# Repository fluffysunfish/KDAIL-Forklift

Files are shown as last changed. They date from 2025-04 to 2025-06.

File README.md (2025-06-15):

# Smart-Forklift

**KDAIL-Forklift** is an intelligent autonomous forklift robot designed as part of a warehouse automation project, built in collaboration with <a href="https://krishnaallied.com/">KDAIL</a>.

# Brief

# Problem statement

Modern warehouses, especially those used by defense orgs face significant challenges in automating indoor material handling tasks due to :
- the lack of GPS 
- the fragmented nature of robotic software stacks  
- security loopholes with proprietery tech 

Existing solutions are often :
- hardware-dependent 
- tailored for specific environments—making them difficult to scale or replicate
- over-complicated and non-intuitive 
- heavily setup dependent 

Moreover, enabling robots to navigate dynamic, cluttered indoor spaces while accurately locating and manipulating goods remains an open problem, especially for small- to medium-scale industries seeking low-cost, swarm-based intelligent automation.

---
# Proposed solution 

We addres these challenges with an end-to-end, modular, and reproducible robotics system tailored for indoor defence warehouse logistics. At its core, the robot fuses <b>UWB-based odometry, 2D LiDAR,</b> and <b>ArUco marker</b> detection to achieve robust SLAM and localization, even in GPS-denied and visually sparse environments. It is capable of autonomously navigating the environment, identifying loads, and executing pick-and-place operations using a forklift actuation mechanism.
The robot is instructed via an intuitive web-based interface backed by a ROS-powered backend, allowing real-time monitoring, control, and task assignment. All hardware—from the custom chassis to sensing and actuation—is designed to be inexpensive and in-house, enabling widespread replication and adoption in budget-constrained setups.

# Features

- 2D LiDAR-based object detection, mapping
- Autonomous navigation and obstacle avoidance
- UWB integration for accurate odometry(sub 5-cms)
- Aruco markers integration for accurate identification and pick-up
- Forklift actuation for pick-and-place
- Simulation + Real-world compatibility
- Modular ROS-based architecture

---

#  Demonstration and Media

- [Automation and detection demo](https://youtube.com/shorts/qDDlVrJwSQA?feature=share)
- [UWB RTLS demo](https://youtube.com/shorts/iG-MlcV99eU?feature=share)

---

## Tech Stack

- **ROS2 Humble** on Ubuntu 22.04
- **Raspberry pi 4b** for onboard compute 
- **LiDAR** (RPLIDAR A2M8) for mapping and detection
- **UWB-anchors and seekers**(DWM30001CDK) for odometry and ranging
- **OpenCV** for computer vision utilities
- **Gazebo** + **RViz** for simulation and visualization
- **ROS-node backed web interface**for cross-platform communication and easy control. 

---

##  Repository Structure

```bash
KDAIL-Forklift/
├── aruco/                  # Scripts to take camera feed, check aruco markers
├── bot_controls/           # Scripts to do teleop and control crane mechanism of the bot
├── ros2_ws/                # Ros workspace of the repository, contains all the nodes and topics created
├── web_control/            # Inuitive UI for over the air communication/control of the bot
├── README.md               # You're here!

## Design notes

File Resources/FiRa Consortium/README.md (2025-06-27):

# FiRa Consortium and Standards
## Table of Contents 
- [What is the FiRa Consortium and why was it established?](#what-is-the-fira-consortium-and-why-was-it-established?)
- [What are the key FiRa specifications and standards?](#what-are-the-key-fira-specifications-and-standards?)
- [Multi-device Ranging
### What is the FiRa Consortium and why was it established?

#### Historical Context and Formation

The Fine Ranging (FiRa) Consortium was established in August 2019 as a direct response to the fragmented state of the UWB industry. Prior to FiRa's formation, the UWB ecosystem suffered from several critical challenges:

**Pre-FiRa Market Conditions:**
- **Proprietary Implementations**: Each vendor developed incompatible UWB solutions
- **Interoperability Gaps**: Devices from different manufacturers couldn't communicate
- **Limited Standardization**: IEEE 802.15.4 provided only PHY/MAC layers
- **Market Fragmentation**: Multiple competing approaches hindered adoption
- **Certification Absence**: No standardized testing or certification programs

**Founding Members and Industry Support:**
The consortium was founded by major technology companies recognizing the need for standardization:

*Original Founding Members:*
- **Apple**: Mobile device integration and user experience
- **Bosch**: Automotive and IoT applications
- **NXP Semiconductors**: Semiconductor solutions and chip design
- **Samsung**: Consumer electronics and smartphone integration
- **Sony**: Consumer electronics and entertainment systems

*Current Membership Growth:*
- **80+ Member Companies**: Representing entire UWB ecosystem
- **Mobile Device Manufacturers**: Apple, Samsung, Google, Xiaomi, Oppo
- **Semiconductor Companies**: NXP, Qorvo, Infineon, STMicroelectronics
- **Automotive Industry**: BMW, Volkswagen, Continental, Hyundai
- **Technology Integrators**: Zebra Technologies, Sewio, Ubisense

#### Mission and Strategic Objectives

**Primary Mission Statement:**
"To drive the adoption of secure fine ranging and positioning capabilities, enabling a new generation of applications and services."

**Strategic Objectives:**

1. **Interoperability Assurance:**
   - Develop comprehensive technical specifications
   - Establish mandatory compliance requirements
   - Create interoperability testing procedures
   - Maintain certification database

2. **Market Acceleration:**
   - Reduce development time and cost
   - Increase consumer and enterprise confidence
   - Enable ecosystem-wide innovation
   - Support regulatory compliance

3. **Security Enhancement:**
   - Establish cryptographic standards
   - Prevent relay and spoofing attacks
   - Enable secure ranging protocols
   - Support privacy protection

4. **Use Case Enablement:**
   - Define application-specific requirements
   - Support vertical market adoption
   - Enable cross-industry collaboration
   - Facilitate regulatory approval

### What are the key FiRa specifications and standards?

#### Core Technical Specifications

**FiRa PHY and MAC Technical Requirements (Current Version 1.3.0):**

*Physical Layer Specifications:*
- **IEEE 802.15.4z Foundation**: Built upon IEEE standard amendment
- **Channel Selection**: Specific channels from 802.15.4z allocation
- **Modulation Schemes**: BPM-BPSK, BPSK with specific parameters
- **Pulse Repetition Frequency**: Defined PRF values for different applications
- **Power Management**: Transmit power control and optimization

*Detailed PHY Parameters:*
```
Channel Specifications:
- Channel 5: 6489.6 MHz center frequency
- Channel 9: 7987.2 MHz center frequency
- Bandwidth: 499.2 MHz nominal
- Pulse Repetition Frequency: 62.4 MHz or 124.8 MHz
- Modulation: BPM-BPSK with spreading factor 128 or 1024
```

*Media Access Control (MAC) Layer:*
- **Frame Structure**: Enhanced 802.15.4z frame format
- **Ranging Protocols**: Two-Way Ranging (TWR) and Time Difference of Arrival (TDoA)
- **Security Integration**: Cryptographic protection mechanisms
- **Multi-device Support**: Concurrent ranging sessions
- **Power Optimization**: Dynamic power management

*MAC Protocol Details:*
- **Ranging Frame Exchange**: Specific timing requirements
- **Acknowledgment Procedures**: Reliable communication protocols
- **Collision Avoidance**: Medium access control mechanisms
- **Synchronization**: Precise timing coordination
- **Error Handling**: Robust error detection and recovery

**FiRa Use Case Requirements (Version 2.0.0):**

*Primary Use Cases:*

1. **Access Control (Use Case 1):**
   - **Application**: Secure vehicle and building access
   - **Ranging Method**: Two-Way Ranging (TWR)
   - **Security Level**: High (AES-128 encryption)
   - **Latency Requirement**: <100 ms for access decision
   - **Accuracy Requirement**: 10-30 cm for proximity detection
   - **Attack Resistance**: Relay attack prevention mandatory

2. **Device-to-Device (Use Case 2):**
   - **Application**: Peer-to-peer device interaction
   - **Ranging Method**: TWR with role switching
   - **Security Level**: Medium to High (application dependent)
   - **Latency Requirement**: <50 ms for responsive interaction
   - **Accuracy Requirement**: 5-20 cm for precise positioning
   - **Multi-device**: Support for multiple simultaneous connections

3. **Point-of-Interest (Use Case 3):**
   - **Application**: Location-based services and navigation
   - **Ranging Method**: TDoA preferred for scalability
   - **Security Level**: Low to Medium (context dependent)
   - **Latency Requirement**: <200 ms for user experience
   - **Accuracy Requirement**: 30-100 cm for zone identification
   - **Scalability**: Support for hundreds of devices

*Extended Use Cases:*
- **Asset Tracking**: Industrial and enterprise applications
- **Augmented Reality**: Spatial computing and AR/VR
- **Smart Home**: IoT device coordination and control
- **Healthcare**: Patient and equipment tracking

**FiRa Test Specifications (Version 1.2.0):**

*Conformance Testing:*
- **Protocol Compliance**: MAC and PHY layer verification
- **Parameter Validation**: Timing, power, and frequency accuracy
- **Message Format**: Frame structure and field validation
- **Error Handling**: Exception and error case testing

*Interoperability Testing:*
- **Cross-vendor Compatibility**: Multi-vendor device testing
- **Use Case Scenarios**: Real-world application testing
- **Performance Validation**: Accuracy and reliability measurement
- **Stress Testing**: High-load and interference scenarios

*Security Testing:*
- **Cryptographic Validation**: Encryption implementation verification
- **Attack Resistance**: Relay and spoofing attack testing
- **Key Management**: Secure key distribution and rotation
- **Privacy Protection**: Personal data protection validation

#### Advanced Technical Features

**Secure Ranging Protocol:**

*Security Architecture:*
The FiRa security model provides multiple layers of protection:

1. **Authentication Layer:**
   - **Mutual Authentication**: Both devices verify identity
   - **Certificate-based**: X.509 certificate validation
   - **Session Establishment**: Secure session key generation
   - **Replay Protection**: Timestamp and nonce validation

2. **Ranging Protection:**
   - **Secure Time Stamps**: Cryptographically protected timing
   - **Message Authentication**: HMAC validation
   - **Sequence Verification**: Prevent message replay
   - **Distance Bounding**: Physical proximity verification

3. **Privacy Protection:**
   - **Identifier Rotation**: Dynamic device identification
   - **Location Privacy**: Prevent unauthorized tracking
   - **Data Minimization**: Limit information exposure
   - **Consent Management**: User privacy controls

*Cryptographic Specifications:*
```
Encryption Algorithms:
- AES-128: Primary encryption standard
- HMAC-SHA256: Message authentication
- ECDH P-256: Key exchange protocol
- HKDF: Key derivation function

Security Parameters:
- Session Key Length: 128 bits
- Nonce Length: 96 bits
- Authentication Tag: 128 bits
- Certificate Chain: Up to 3 levels
```

**Multi-device Ranging:**

*Concurrent Ranging Sessions:*
FiRa supports sophisticated multi-device scenarios:

1. **Round-Robin Ranging:**
   - **Sequential Measurement**: One device ranges to multiple anchors
   - **Timing Coordination**: Precise scheduling to avoid interference
   - **Scalability**: Support for 8+ concurrent sessions
   - **Efficiency**: Optimized for battery-powered devices

2. **Simultaneous Ranging:**
   - **Parallel Measurement**: Multiple devices range simultaneously
   - **Code Division**: Orthogonal codes prevent interference
   - **Synchronization**: Precise timing across all devices
   - **Collision Management**: Automatic conflict resolution

3. **Hierarchical Networks:**
   - **Master-Slave Architecture**: Coordinated multi-device systems
   - **Cascaded Ranging**: Extended coverage through device chaining
   - **Load Balancing**: Distribute ranging load across network
   - **Fault Tolerance**: Redundant paths and backup systems

**Angle-of-Arrival Integration:**

*Enhanced Positioning:*
FiRa specifications include provisions for AoA enhancement:

1. **Antenna Array Support:**
   - **Spatial Diversity**: Multiple antenna elements
   - **Beam Forming**: Directional transmission and reception
   - **Calibration**: Precise antenna array characterization
   - **Temperature Compensation**: Environmental stability

2. **Angle Measurement:**
   - **Phase Difference**: Based on signal phase relationships
   - **Amplitude Comparison**: Signal strength at different elements
   - **Time Difference**: Arrival time variations across array
   - **Hybrid Methods**: Combined ranging and angle measurement

3. **Enhanced Accuracy:**
   - **2D Positioning**: Improved with angle information
   - **3D Positioning**: Full spatial positioning capability
   - **Orientation Detection**: Device attitude determination
   - **Reduced Infrastructure**: Fewer anchors required

### How does FiRa certification ensure interoperability between UWB devices?

#### Comprehensive Certification Framework

**Certification Philosophy:**
FiRa's certification approach is built on the principle that true interoperability requires testing beyond basic protocol compliance. The program validates not just technical conformance, but real-world operational compatibility across diverse scenarios and vendor implementations.

**Multi-tiered Certification Structure:**

*Tier 1: Component Certification*
- **Scope**: Individual UWB chips, modules, and subsystems
- **Testing Focus**: PHY and MAC layer compliance
- **Requirements**: Protocol conformance and parameter validation
- **Documentation**: Detailed test reports and compliance matrices
- **Validity**: Component-level certification for integration

*Tier 2: Product Certification*
- **Scope**: Complete end-user devices and systems
- **Testing Focus**: Full system integration and performance
- **Requirements**: Use case compliance and interoperability
- **Documentation**: System-level validation and user guides
- **Validity**: Product-level certification for market deployment

*Tier 3: Ecosystem Certification*
- **Scope**: Multi-vendor system integration
- **Testing Focus**: Cross-vendor interoperability validation
- **Requirements**: Real-world scenario testing
- **Documentation**: Ecosystem compatibility reports
- **Validity**: System-level deployment certification

#### Detailed Testing Methodology

**Conformance Testing Procedures:**

*Physical Layer Validation:*
```
Test Categories:
1. Transmitter Tests:
   - Power spectral density measurement
   - Frequency accuracy and stability
   - Pulse shape and timing accuracy
   - Modulation quality assessment

2. Receiver Tests:
   - Sensitivity and dynamic range
   - Frequency selectivity and blocking
   - Spurious response rejection
   - Demodulation accuracy

3. Ranging Tests:
   - Time-of-flight accuracy
   - Ranging precision and repeatability
   - Multi-path handling capability
   - NLOS detection and mitigation
```

*MAC Layer Validation:*
- **Frame Structure**: Compliance with FiRa frame formats
- **Timing Requirements**: Precise inter-frame spacing
- **Acknowledgment Protocols**: Reliable message exchange
- **Error Handling**: Robust error detection and recovery
- **Security Integration**: Cryptographic protocol implementation

*Application Layer Testing:*
- **Use Case Compliance**: Specific application requirements
- **Performance Metrics**: Accuracy, latency, and reliability measurements
- **Security Validation**: End-to-end security implementation
- **User Experience**: Human-machine interface compliance
- **Environmental Testing**: Performance across operating conditions

**Interoperability Testing Protocol:**

*Cross-Vendor Compatibility Matrix:*
```
Testing Scenarios:
┌─────────────┬─────────────┬─────────────┬─────────────┐
│   Vendor    │   Vendor A  │   Vendor B  │   Vendor C  │
├─────────────┼─────────────┼─────────────┼─────────────┤
│  Vendor A   │    N/A      │   Required  │   Required  │
│  Vendor B   │  Required   │    N/A      │   Required  │
│  Vendor C   │  Required   │   Required  │    N/A      │
└─────────────┴─────────────┴─────────────┴─────────────┘

Test Matrix Requirements:
- All vendor pairs must pass interoperability tests
- Minimum 3 vendors required for ecosystem validation
- Testing covers all supported use cases
- Performance benchmarks must be maintained
```

*Real-World Scenario Testing:*
1. **Office Environment:**
   - Multiple anchor deployment
   - Personnel and asset tracking
   - WiFi interference scenarios
   - Mixed vendor equipment

2. **Industrial Environment:**
   - Metal structure reflections
   - High-temperature operation
   - Electromagnetic interference
   - Safety system integration

3. **Automotive Environment:**
   - Vehicle access scenarios
   - Parking lot deployment
   - Mobile device integration
   - Security attack resistance

4. **Consumer Environment:**
   - Home automation integration
   - Mobile device interaction
   - Privacy protection validation
   - User experience testing

#### Certification Process Workflow

**Pre-Certification Phase:**

*Self-Assessment Tools:*
- **FiRa Test Suite**: Automated testing software
- **Reference Implementation**: Validated software stack
- **Compliance Checklist**: Detailed requirement verification
- **Pre-certification Report**: Internal validation documentation

*Technical Documentation Requirements:*
- **Hardware Design**: Detailed circuit and antenna designs
- **Software Architecture**: Protocol stack implementation
- **Security Implementation**: Cryptographic module documentation
- **Performance Characterization**: Laboratory test results
- **Environmental Testing**: Temperature, humidity, vibration results

**Authorized Test Laboratory (ATL) Testing:**

*Accredited Facilities:*
FiRa maintains a network of authorized test laboratories worldwide:

- **Geographic Coverage**: Major markets globally covered
- **Accreditation Standards**: ISO/IEC 17025 compliance
- **Equipment Calibration**: Traceable measurement standards
- **Test Procedure Training**: FiRa-certified test engineers
- **Quality Assurance**: Regular proficiency testing

*Testing Infrastructure Requirements:*
```
Laboratory Equipment:
1. RF Test Equipment:
   - Vector network analyzers (10 MHz - 20 GHz)
   - Spectrum analyzers with UWB capability
   - Signal generators with arbitrary waveform
   - Power meters and sensors

2. Positioning Test Setup:
   - Anechoic chamber (3m x 3m minimum)
   - Precision positioning systems
   - Environmental control systems
   - Multi-path simulation capability

3. Security Test Equipment:
   - Hardware security modules
   - Cryptographic test vectors
   - Side-channel analysis tools
   - Protocol analysis equipment
```

**Certification Decision Process:**

*Technical Review Board:*
- **Composition**: Industry experts from member companies
- **Review Process**: Independent technical assessment
- **Decision Criteria**: Objective pass/fail requirements
- **Appeal Process**: Structured dispute resolution
- **Continuous Monitoring**: Post-certification surveillance

*Certification Maintenance:*
- **Annual Reviews**: Ongoing compliance verification
- **Change Notifications**: Product modification reporting
- **Re-testing Requirements**: Significant change validation
- **Market Surveillance**: Field performance monitoring
- **Corrective Actions**: Non-compliance remediation

#### Quality Assurance and Validation

**Test Result Validation:**

*Statistical Analysis:*
- **Measurement Uncertainty**: Quantified test accuracy
- **Repeatability**: Multiple test run consistency
- **Reproducibility**: Inter-laboratory agreement
- **Confidence Intervals**: Statistical significance testing
- **Outlier Detection**: Anomalous result identification

*Performance Benchmarking:*
```
Key Performance Indicators (KPIs):
1. Ranging Accuracy:
   - Mean absolute error: <30 cm (95% confidence)
   - Standard deviation: <15 cm
   - Maximum error: <100 cm

2. Latency Performance:
   - Average ranging time: <10 ms
   - Maximum ranging time: <50 ms
   - System response time: <100 ms

3. Reliability Metrics:
   - Packet success rate: >99%
   - False alarm rate: <0.1%
   - Availability: >99.9%

4. Security Validation:
   - Attack resistance: 100% (no successful attacks)
   - Key management: Proper implementation
   - Privacy protection: Compliance verified
```

**Continuous Improvement Process:**

*Feedback Integration:*
- **Field Experience**: Real-world deployment feedback
- **Member Input**: Industry stakeholder requirements
- **Technology Evolution**: Emerging capability integration
- **Regulatory Changes**: Compliance requirement updates
- **Security Threats**: New attack vector mitigation

*Specification Updates:*
- **Regular Revision Cycle**: Annual specification reviews
- **Backward Compatibility**: Legacy device support
- **Migration Paths**: Upgrade roadmap definition
- **Implementation Guidance**: Best practice documentation
- **Training Programs**: Industry education initiatives

### What is the difference between IEEE 802.15.4z and FiRa specifications?

#### Fundamental Scope and Purpose Differences

**IEEE 802.15.4z Amendment (2020):**

*Standards Development Context:*
IEEE 802.15.4z represents a formal amendment to the IEEE 802.15.4 standard, specifically targeting Ultra Wideband (UWB) applications. The development process followed IEEE's rigorous standards development procedures:

- **Development Timeline**: 2016-2020 (4-year development cycle)
- **Working Group**: IEEE 802.15.4z Task Group
- **Consensus Process**: Global industry participation and voting
- **Scope Limitation**: Intentionally limited to PHY and MAC layers
- **Implementation Flexibility**: Multiple optional features and parameters

*Technical Architecture:*
```
IEEE 802.15.4z Layer Structure:
┌─────────────────────────────────────┐
│        Application Layer            │ ← Not Specified
├─────────────────────────────────────┤
│        Network Layer               │ ← Not Specified
├─────────────────────────────────────┤
│    Logical Link Control (LLC)      │ ← Not Specified
├─────────────────────────────────────┤
│   Medium Access Control (MAC)      │ ← IEEE 802.15.4z
├─────────────────────────────────────┤
│      Physical Layer (PHY)          │ ← IEEE 802.15.4z
└─────────────────────────────────────┘
```

**FiRa Consortium Specifications:**

*Industry Requirements Focus:*
FiRa specifications were developed to address real-world deployment needs that IEEE 802.15.4z, by design, does not cover:

- **Development Timeline**: 2019-ongoing (continuous evolution)
- **Industry Consortium**: Commercial deployment focus
- **Comprehensive Scope**: Full protocol stack specification
- **Prescriptive Requirements**: Specific mandatory implementations
- **Market-Driven Features**: User experience and security emphasis

*Complete System Architecture:*
```
FiRa Specification Coverage:
┌─────────────────────────────────────┐
│     Application Profiles           │ ← FiRa Use Cases
├─────────────────────────────────────┤
│     Security Framework             │ ← FiRa Security
├─────────────────────────────────────┤
│     Service Layer                  │ ← FiRa Services
├─────────────────────────────────────┤
│   Medium Access Control (MAC)      │ ← FiRa + IEEE 802.15.4z
├─────────────────────────────────────┤
│      Physical Layer (PHY)          │ ← FiRa + IEEE 802.15.4z
└─────────────────────────────────────┘
```

#### Detailed Technical Specification Comparison

**Physical Layer Implementation:**

*IEEE 802.15.4z PHY Specification:*
- **Channel Definition**: Defines available UWB channels
- **Modulation Options**: Multiple modulation schemes (BPM-BPSK, BPSK)
- **Parameter Ranges**: Wide ranges for implementation flexibility
- **Power Control**: Basic transmit power management
- **Implementation Choice**: Vendors select from multiple options

*Detailed IEEE 802.15.4z PHY Parameters:*
```
Channel Allocations:
- Channel 5: 6489.6 MHz ± 2.5 MHz
- Channel 6: 6988.8 MHz ± 2.5 MHz
- Channel 8: 7987.2 MHz ± 2.5 MHz
- Channel 9: 8486.4 MHz ± 2.5 MHz

Modulation Schemes:
- BPM-BPSK: Binary Phase Modulation with BPSK
- BPM-QPSK: Binary Phase Modulation with QPSK
- Spreading Factors: 32, 64, 128, 1024

PRF Options:
- 62.4 MHz: Standard pulse repetition frequency
- 124.8 MHz: High pulse repetition frequency
- 249.6 MHz: Very high pulse repetition frequency
```

*FiRa PHY Profile Selection:*
FiRa specifies exact parameter combinations for interoperability:
- **Mandatory Channels**: Channel 5 (6489.6 MHz) and Channel 9 (7987.2 MHz)
- **Required Modulation**: BPM-BPSK with specific spreading factors
- **Fixed PRF**: 62.4 MHz for standard operation
- **Power Profiles**: Specific power levels for different use cases
- **Antenna Requirements**: Detailed antenna specifications

**Medium Access Control Layer:**

*IEEE 802.15.4z MAC Features:*
- **Frame Structure**: Enhanced frame format with security
- **Ranging Methods**: Two-Way Ranging (TWR) and Enhanced SDS-TWR
- **Security Options**: Multiple authentication and encryption options
- **Timing Control**: Precise timing for ranging accuracy
- **Multi-device Support**: Basic multi-device ranging capability

*MAC Protocol Details:*
```
IEEE 802.15.4z Frame Types:
1. Ranging Initiation (RFRAME):
   - Sequence Number: 8 bits
   - Ranging Counter: 16 bits
   - Message Authentication Code: Variable

2. Ranging Response (RFRAME):
   - Response Delay: 32 bits
   - Ranging Counter: 16 bits
   - Round Trip Time: 32 bits

3. Ranging Final (RFRAME):
   - Final Delay: 32 bits
   - Response RX Time: 32 bits
   - Final TX Time: 32 bits
```

*FiRa MAC Profile Implementation:*
- **Specific Frame Usage**: Mandatory frame types and fields
- **Timing Parameters**: Exact timing requirements for interoperability
- **Security Implementation**: Specific cryptographic algorithms
- **Multi-device Protocols**: Detailed scheduling and coordination
- **Error Handling**: Comprehensive error recovery procedures

**Security Architecture Comparison:**

*IEEE 802.15.4z Security Foundation:*
The IEEE standard provides basic security building blocks:

1. **Authentication Methods:**
   - Shared Key Authentication
   - Certificate-based Authentication
   - Multiple key derivation options

2. **Encryption Capabilities:**
   - AES-128 Counter Mode (CTR)
   - AES-128 Counter with CBC-MAC (CCM)
   - Variable security levels

3. **Integrity Protection:**
   - Message Authentication Codes (MAC)
   - Sequence number protection
   - Timestamp validation

*FiRa Security Profile Requirements:*
FiRa builds comprehensive security on IEEE foundations:

1. **Mandatory Security Features:**
   ```
   Cryptographic Requirements:
   - Encryption: AES-128 CCM mode (mandatory)
   - Authentication: HMAC-SHA256
   - Key Exchange: ECDH P-256
   - Key Derivation: HKDF-SHA256
   
   Security Policies:
   - Session keys must be rotated every 1000 transactions
   - Replay protection with 32-bit sequence numbers
   - Secure timestamp validation (±1ms tolerance)
   - Certificate chain validation (up to 3 levels)
   ```

2. **Attack Resistance Requirements:**
   - **Relay Attack Prevention**: Cryptographic distance bounding
   - **Spoofing Protection**: Mutual authentication mandatory
   - **Eavesdropping Resistance**: Perfect forward secrecy
   - **Jamming Mitigation**: Frequency hopping and power control

3. **Privacy Protection:**
   - **Identifier Rotation**: Dynamic device ID changing
   - **Location Privacy**: Anonymized positioning data
   - **Consent Management**: User control over data sharing
   - **Data Minimization**: Limit information collection

#### Implementation and Compliance Differences

**Implementation Flexibility:**

*IEEE 802.15.4z Approach:*
- **Design Philosophy**: Maximum implementation flexibility
- **Optional Features**: Many features marked as optional
- **Parameter Ranges**: Wide parameter ranges allowed
- **Vendor Differentiation**: Encourages unique implementations
- **Minimal Mandatory**: Only essential features required

*Example Implementation Choices:*
```
IEEE 802.15.4z Options:
Channel Selection:
- Required: Any valid UWB channel
- Optional: Channel switching capability
- Implementation: Vendor-specific selection

Security Level:
- Required: Basic authentication
- Optional: Advanced encryption
- Implementation: Vendor-specific policies

Ranging Methods:
- Required: Basic TWR
- Optional: Enhanced methods
- Implementation: Vendor-specific algorithms
```

*FiRa Prescriptive Approach:*
- **Design Philosophy**: Guaranteed interoperability
- **Mandatory Features**: Specific features required for certification
- **Fixed Parameters**: Exact parameter values specified
- **Uniform Implementation**: Consistent behavior across vendors
- **Comprehensive Requirements**: All aspects specified

*FiRa Implementation Mandates:*
```
FiRa Mandatory Requirements:
Channel Selection:
- Required: Channel 5 AND Channel 9 support
- Mandatory: Automatic channel selection
- Implementation: FiRa-specified algorithm

Security Implementation:
- Required: Full security suite
- Mandatory: All cryptographic features
- Implementation: FiRa test vectors

Ranging Performance:
- Required: <30cm accuracy (95% confidence)
- Mandatory: <10ms latency
- Implementation: FiRa test scenarios
```

**Testing and Certification:**

*IEEE 802.15.4z Conformance:*
- **Basic Compliance**: Protocol conformance testing only
- **Limited Scope**: PHY and MAC layer validation
- **Implementation Variation**: Different implementations may not interoperate
- **No Certification**: IEEE provides standard, not certification

*FiRa Comprehensive Certification:*
- **Full System Testing**: End-to-end system validation
- **Interoperability Focus**: Cross-vendor compatibility required
- **Real-world Scenarios**: Application-specific testing
- **Continuous Certification**: Ongoing compliance monitoring

#### Market Adoption and Ecosystem Impact

**Standards Adoption Patterns:**

*IEEE 802.15.4z Market Impact:*
- **Technology Foundation**: Provides technical basis for UWB systems
- **Vendor Innovation**: Enables proprietary enhancements
- **Fragmented Ecosystem**: Different implementations may not interoperate
- **Long-term Stability**: Formal standard provides stability

*FiRa Specification Market Impact:*
- **Immediate Interoperability**: Devices work together out-of-box
- **Faster Time-to-Market**: Reduced development and testing time
- **Ecosystem Growth**: Accelerated market adoption
- **User Confidence**: Certified compatibility assurance

**Industry Integration Strategy:**

*Complementary Relationship:*
Rather than competing, IEEE 802.15.4z and FiRa specifications complement each other:

1. **Foundation and Implementation:**
   - IEEE 802.15.4z: Technical foundation
   - FiRa: Commercial implementation guide

2. **Standards and Certification:**
   - IEEE 802.15.4z: Formal international standard
   - FiRa: Industry certification program

3. **Innovation and Interoperability:**
   - IEEE 802.15.4z: Enables innovation
   - FiRa: Ensures interoperability

4. **Long-term Evolution:**
   - IEEE 802.15.4z: Stable technical base
   - FiRa: Rapid market adaptation

---

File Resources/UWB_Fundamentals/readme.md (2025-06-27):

# UWB Fundamentals, Technical Details, Comparison with other technologies for RTLS 

## Table of Contents
- [UWB Technology Fundamentals](#uwb-technology-fundamentals)
- [Key advantages of UWB for positioning systems?](#what-are-the-key-advantages-of-uwb-for-positioning-systems)
- [How does UWB compare to other positioning technologies?](#how-does-uwb-compare-to-other-positioning-technologies?)
- [What frequency bands does UWB operate in and why?](#what-frequency-bands-does-UWB-operate-in-and-why?)
---

## UWB Technology Fundamentals

### What is Ultra-Wideband (UWB) technology and how does it work?

Ultra-Wideband (UWB) is a revolutionary short-range wireless communication technology that fundamentally differs from conventional narrowband systems. Instead of using a narrow frequency channel, UWB spreads its signal across an extremely wide bandwidth, typically exceeding 500 MHz.

#### Core Technical Principles

**Pulse-Based Transmission Architecture:**
UWB operates on the principle of transmitting extremely short pulses (typically 0.5 to 2 nanoseconds in duration) with very low duty cycles (often less than 1%). These pulses are transmitted across the entire allocated frequency spectrum simultaneously, creating a spread spectrum signal.

**Mathematical Foundation:**
The fundamental UWB signal can be represented as:
```
s(t) = Σ w(t - jTf - cjTc)
```
Where:
- w(t) = transmitted pulse waveform
- Tf = frame period
- Tc = chip period
- cj = pseudo-random time-hopping code

**Frequency Domain Characteristics:**
- **Bandwidth**: Minimum 500 MHz (typically 1.5-7.5 GHz)
- **Power Spectral Density**: Extremely low (-41.3 dBm/MHz in US)
- **Fractional Bandwidth**: >20% or >500 MHz (whichever is smaller)
- **Center Frequency**: Variable across 3.1-10.6 GHz range

#### Physical Layer Operation

**Pulse Generation Methods:**

1. **Gaussian Pulse Generation:**
   - Uses Gaussian derivatives for pulse shaping
   - Provides clean spectral characteristics
   - Enables precise timing measurements
   - Mathematical representation: Gaussian derivatives of order n

2. **Impulse Radio (IR-UWB):**
   - Transmits very short pulses without carrier
   - Each pulse occupies entire frequency band
   - Information encoded in pulse position, amplitude, or polarity
   - Extremely low power consumption per bit

**Modulation Schemes:**
- **Pulse Position Modulation (PPM)**: Information in pulse timing
- **Pulse Amplitude Modulation (PAM)**: Information in pulse amplitude
- **On-Off Keying (OOK)**: Information in pulse presence/absence
- **Binary Phase Shift Keying (BPSK)**: Information in pulse polarity

#### Signal Processing Fundamentals

**Receiver Architecture:**
UWB receivers must capture and process signals across the entire bandwidth simultaneously. This requires:

1. **Wide-band Front-end:**
   - Low-noise amplification across full bandwidth
   - Minimal group delay variation
   - High dynamic range capability

2. **Analog-to-Digital Conversion:**
   - High sampling rates (typically 1-2 GHz)
   - High resolution (12-16 bits)
   - Precise timing synchronization

3. **Digital Signal Processing:**
   - Matched filtering for optimal signal detection
   - Timing acquisition and tracking
   - Channel estimation and equalization

**Time-of-Flight Measurement:**
The core principle enabling precise ranging is time-of-flight measurement:
```
Distance = (Time-of-Flight × Speed of Light) / 2
```

For centimeter-level accuracy, timing precision must be:
- 1 cm accuracy requires ~67 picoseconds timing precision
- 10 cm accuracy requires ~667 picoseconds timing precision

#### Propagation Characteristics

**Free Space Propagation:**
UWB signals follow the Friis transmission equation:
```
Pr = Pt × Gt × Gr × (λ/4πd)²
```
Where:
- Pr = received power
- Pt = transmitted power
- Gt, Gr = transmit and receive antenna gains
- λ = wavelength
- d = distance

**Multipath Propagation:**
UWB's wide bandwidth provides exceptional multipath resolution:
- **Delay Resolution**: ~1/(2×Bandwidth)
- **For 1 GHz bandwidth**: ~0.5 nanosecond resolution
- **Spatial Resolution**: ~15 cm path difference detection

**Penetration Capabilities:**
- **Drywall**: 5-10 dB loss, maintains ranging capability
- **Concrete**: 20-30 dB loss, significant range reduction
- **Metal**: Near-complete blocking, requires line-of-sight
- **Human Body**: 10-15 dB loss, causes ranging bias

### What are the key advantages of UWB for positioning systems?

#### Precision and Accuracy Advantages

**Temporal Resolution:**
UWB's wide bandwidth provides exceptional temporal resolution, enabling precise time-of-flight measurements:

- **Bandwidth-Limited Resolution**: Δt ≈ 1/(2×B)
- **For 1 GHz bandwidth**: ~0.5 ns resolution
- **Distance Precision**: ~7.5 cm theoretical limit
- **Practical Accuracy**: 10-30 cm with proper implementation

**Multipath Mitigation:**
The wide bandwidth enables UWB to resolve multipath components that would interfere with narrowband systems:

1. **Path Separation**: Can distinguish paths separated by >15 cm
2. **Leading Edge Detection**: Algorithms can identify direct path
3. **Rake Receiver**: Can combine multiple paths for improved SNR
4. **NLOS Detection**: Can identify and compensate for blocked paths

**Cramér-Rao Lower Bound (CRLB):**
The theoretical limit of ranging accuracy is given by:
```
σ²(τ) ≥ 1/(8π²β²SNR)
```
Where:
- β = effective bandwidth
- SNR = signal-to-noise ratio
- τ = time delay estimate

#### Operational Benefits

**Interference Immunity:**
UWB's spread spectrum nature provides exceptional interference resistance:

- **Processing Gain**: ~10×log₁₀(Spreading Factor)
- **Typical Values**: 20-30 dB processing gain
- **Coexistence**: Operates below noise floor of other systems
- **Jamming Resistance**: Difficult to jam due to spread spectrum

**Power Efficiency:**
UWB's low duty cycle and spreading gain enable efficient operation:

- **Duty Cycle**: Typically <1%
- **Average Power**: Much lower than peak power
- **Battery Life**: Extended operation for mobile devices
- **Regulatory Compliance**: Stays within power spectral density limits

**Penetration and Coverage:**
UWB provides unique propagation characteristics:

- **Non-Line-of-Sight**: Can work through some obstacles
- **Multiple Zones**: Can track through walls (with accuracy reduction)
- **Consistent Performance**: Less affected by environmental changes
- **All-Weather**: Unaffected by atmospheric conditions

#### System-Level Advantages

**Real-Time Performance:**
UWB enables low-latency positioning systems:

- **Measurement Time**: Microsecond-level ranging transactions
- **Update Rates**: 10-100 Hz positioning updates possible
- **Latency**: <10 ms total system latency achievable
- **Deterministic**: Predictable timing behavior

**Scalability:**
UWB systems can support large numbers of devices:

- **Multiple Access**: Time-division or code-division multiplexing
- **Collision Avoidance**: MAC protocols prevent interference
- **Network Capacity**: Hundreds of devices per anchor network
- **Distributed Processing**: Computation can be distributed

**Security Features:**
UWB provides inherent security advantages:

- **Low Probability of Intercept**: Spread spectrum nature
- **Distance Bounding**: Physical security through ranging
- **Replay Attack Resistance**: Timing-based authentication
- **Secure Ranging**: Cryptographic time-of-flight protection

### How does UWB compare to other positioning technologies?

#### Detailed Technology Comparison

**Ultra-Wideband (UWB):**
- **Frequency**: 3.1-10.6 GHz (unlicensed globally)
- **Bandwidth**: 500 MHz - 7.5 GHz
- **Accuracy**: 10-30 cm (optimal), 50 cm-1 m (typical)
- **Range**: 10-200 m (depending on environment)
- **Power**: 1-100 mW (application dependent)
- **Latency**: <10 ms
- **Capacity**: 100+ devices per network
- **Cost**: $5-50 per device (volume dependent)
- **Infrastructure**: Requires 3-4 anchor points minimum

**WiFi Round-Trip Time (RTT):**
- **Frequency**: 2.4/5 GHz (shared spectrum)
- **Bandwidth**: 20-160 MHz
- **Accuracy**: 1-3 m (optimal), 3-10 m (typical)
- **Range**: 50-100 m indoor
- **Power**: 100-1000 mW
- **Latency**: 50-500 ms
- **Capacity**: 50-100 devices per access point
- **Cost**: $1-10 per device (leverages existing WiFi)
- **Infrastructure**: Uses existing WiFi access points

**Bluetooth Angle-of-Arrival (AoA):**
- **Frequency**: 2.4 GHz ISM band
- **Bandwidth**: 2 MHz
- **Accuracy**: 0.5-2 m (optimal), 2-5 m (typical)
- **Range**: 10-50 m
- **Power**: 1-10 mW
- **Latency**: 100-1000 ms
- **Capacity**: 20-50 devices per locator
- **Cost**: $2-20 per device
- **Infrastructure**: Requires AoA-capable access points

**Global Navigation Satellite Systems (GNSS/GPS):**
- **Frequency**: L1 (1575 MHz), L2 (1227 MHz), L5 (1176 MHz)
- **Bandwidth**: 2-20 MHz
- **Accuracy**: 3-5 m (standard), 10 cm (RTK)
- **Range**: Global coverage
- **Power**: 50-500 mW
- **Latency**: 1-30 seconds (depending on mode)
- **Capacity**: Unlimited (receive-only)
- **Cost**: $1-1000 per receiver
- **Infrastructure**: Satellite constellation

#### Environmental Performance Analysis

**Indoor Environments:**

*UWB Performance:*
- **Multipath Handling**: Excellent due to wide bandwidth
- **Penetration**: Can work through walls with reduced accuracy
- **Interference**: Minimal due to spread spectrum
- **Deployment**: Requires site survey and anchor installation

*WiFi RTT Performance:*
- **Multipath Handling**: Poor, causes significant ranging errors
- **Penetration**: Good, leverages existing coverage
- **Interference**: Significant in dense WiFi environments
- **Deployment**: Leverages existing infrastructure

*Bluetooth AoA Performance:*
- **Multipath Handling**: Moderate, angle measurements affected
- **Penetration**: Limited, requires line-of-sight for best performance
- **Interference**: Moderate in crowded 2.4 GHz band
- **Deployment**: Requires specialized anchor hardware

**Outdoor Environments:**

*UWB Performance:*
- **Line-of-Sight**: Excellent performance in open areas
- **Obstacles**: Degrades significantly with blockage
- **Weather**: Unaffected by atmospheric conditions
- **Range**: Limited to ~200 m maximum

*GNSS Performance:*
- **Open Sky**: Excellent accuracy and availability
- **Urban Canyon**: Significant degradation due to multipath
- **Indoor**: Complete failure in most cases
- **Weather**: Minimal impact on performance

#### Application-Specific Suitability

**Asset Tracking:**
- **UWB**: Best for high-value assets requiring precise location
- **WiFi**: Good for general asset tracking with existing infrastructure
- **Bluetooth**: Suitable for consumer devices and IoT sensors
- **GNSS**: Ideal for outdoor vehicle and equipment tracking

**Personnel Safety:**
- **UWB**: Excellent for emergency response and hazardous environments
- **WiFi**: Good for general personnel tracking in office environments
- **Bluetooth**: Suitable for consumer health and fitness tracking
- **GNSS**: Essential for outdoor worker safety

**Automation and Robotics:**
- **UWB**: Preferred for autonomous vehicle navigation
- **WiFi**: Suitable for general robotic positioning
- **Bluetooth**: Limited to simple proximity-based applications
- **GNSS**: Essential for outdoor autonomous systems

### What frequency bands does UWB operate in and why?

#### Global Frequency Allocations

**United States (Federal Communications Commission - FCC):**

*Primary UWB Allocation:*
- **Frequency Range**: 3.1 - 10.6 GHz
- **Bandwidth**: 7.5 GHz total spectrum
- **Power Limit**: -41.3 dBm/MHz EIRP (equivalent to 0.5 mW/MHz)
- **Regulatory Part**: 47 CFR Part 15.515
- **Emission Designation**: Ultra-wideband intentional radiator

*Sub-band Restrictions:*
- **3.1-3.4 GHz**: Coordination required near radio astronomy sites
- **5.725-5.875 GHz**: Reduced power in some applications
- **8.5-10.6 GHz**: Full power permitted for all applications

*Detection and Avoidance:*
- **DAA Requirements**: Mandatory for certain frequency ranges
- **Adaptive Power Control**: Required in some bands
- **Sensing Thresholds**: Specific detection requirements

**Europe (European Telecommunications Standards Institute - ETSI):**

*Band Allocations:*
- **Band 1**: 3.1 - 4.8 GHz (indoor and outdoor use)
- **Band 2**: 6.0 - 8.5 GHz (indoor use only)
- **Band 3**: 8.5 - 10.6 GHz (indoor use only)

*Power Regulations:*
- **Indoor Limit**: -41.3 dBm/MHz EIRP
- **Outdoor Limit**: -70 dBm/MHz EIRP (significantly reduced)
- **Mitigation Techniques**: TPC and DAA required

*Specific Country Variations:*
- **Germany**: Additional restrictions below 6 GHz
- **France**: Specific automotive radar coordination
- **UK**: Post-Brexit alignment with EU regulations

**Asia-Pacific Regions:**

*Japan (Ministry of Internal Affairs and Communications - MIC):*
- **Band 1**: 3.4 - 4.8 GHz (indoor use)
- **Band 2**: 7.25 - 10.25 GHz (indoor use)
- **Power Limit**: -41.3 dBm/MHz EIRP
- **Special Provisions**: Automotive radar coordination

*South Korea (Korea Communications Commission - KCC):*
- **Band 1**: 3.1 - 4.8 GHz
- **Band 2**: 7.2 - 10.2 GHz
- **Power Limit**: -41.3 dBm/MHz EIRP
- **Certification**: K-mark certification required

*Singapore (Info-communications Media Development Authority - IMDA):*
- **Band 1**: 3.4 - 4.2 GHz
- **Band 2**: 6.0 - 9.0 GHz
- **Power Limit**: -41.3 dBm/MHz EIRP
- **Restrictions**: Indoor use only

*Australia (Australian Communications and Media Authority - ACMA):*
- **Frequency Range**: 3.4 - 4.2 GHz and 6.0 - 8.5 GHz
- **Power Limit**: -41.3 dBm/MHz EIRP
- **Usage**: Indoor applications only

#### Technical Rationale for Frequency Selection

**Propagation Characteristics:**

*Path Loss Considerations:*
The free-space path loss increases with frequency according to:
```
PL(dB) = 20×log₁₀(f) + 20×log₁₀(d) + 20×log₁₀(4π/c)
```

*Frequency-Specific Behavior:*
- **3-4 GHz**: Good propagation, some wall penetration
- **6-8 GHz**: Balanced range and precision
- **8-10 GHz**: High precision, limited penetration

*Multipath Characteristics:*
- **Lower Frequencies**: Longer multipath delays, more reflections
- **Higher Frequencies**: Shorter delays, more absorption
- **Optimal Range**: 6-8 GHz provides best balance

**Antenna Design Considerations:**

*Physical Constraints:*
- **Antenna Size**: Inversely proportional to frequency
- **3-4 GHz**: Larger antennas, better gain
- **8-10 GHz**: Smaller antennas, easier integration
- **Bandwidth**: Wide bandwidth requires careful design

*Efficiency Factors:*
- **Bandwidth Efficiency**: Wider bandwidth improves ranging
- **Gain-Bandwidth Product**: Fundamental antenna limitation
- **Manufacturing Tolerance**: Higher frequencies more sensitive

**Regulatory Harmony:**

*Global Standardization:*
- **ITU Regions**: Alignment across different regions
- **WRC Decisions**: World Radiocommunication Conference outcomes
- **Industry Coordination**: Equipment manufacturer requirements

*Interference Mitigation:*
- **Existing Services**: Radar, satellite, radio astronomy
- **Coexistence Studies**: Extensive interference analysis
- **Protection Criteria**: Specific interference thresholds

#### Spectrum Efficiency and Coexistence

**Power Spectral Density Limits:**

*Regulatory Justification:*
The -41.3 dBm/MHz limit ensures:
- **Noise Floor Operation**: UWB signals appear as noise
- **Interference Protection**: Minimal impact on existing services
- **Detection Threshold**: Below typical receiver sensitivity

*Technical Implementation:*
- **Spreading Factor**: Wide bandwidth reduces power density
- **Duty Cycle**: Low duty cycle further reduces average power
- **Adaptive Control**: Dynamic power adjustment based on environment

**Coexistence Mechanisms:**

*Detect and Avoid (DAA):*
- **Sensing Capability**: Detect incumbent signals
- **Avoidance Strategy**: Reduce power or change frequency
- **Implementation**: Real-time spectrum monitoring

*Transmit Power Control (TPC):*
- **Adaptive Power**: Adjust based on link requirements
- **Interference Minimization**: Reduce unnecessary emissions
- **Efficiency Optimization**: Balance performance and coexistence

**Future Spectrum Considerations:**

*6 GHz Expansion:*
- **Additional Spectrum**: 5.925-7.125 GHz under consideration
- **WiFi 6E Impact**: Shared spectrum challenges
- **Coordination Requirements**: Complex interference scenarios

*Millimeter Wave Integration:*
- **60 GHz Bands**: Potential for very high precision
- **Atmospheric Absorption**: Range limitations
- **Application Niches**: Specific use cases only

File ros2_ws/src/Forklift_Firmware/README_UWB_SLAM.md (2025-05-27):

# UWB-Based Static SLAM System

This package provides a static SLAM (Simultaneous Localization and Mapping) system that uses UWB (Ultra-Wideband) sensors for robot positioning and IMU for orientation, combined with LiDAR data for mapping.

## System Overview

The system consists of:
- **UWB positioning**: 4 anchors at rectangle corners + 1 tag on robot
- **IMU orientation**: Provides robot yaw angle
- **LiDAR mapping**: Creates occupancy grid map
- **Static SLAM**: Builds map using known robot position

## Hardware Setup

### UWB Anchor Configuration
```
Anchor 2 (0, Y_max)  -------- Anchor 3 (X_max, Y_max)
|                                                    |
|                                                    |
|                Robot with UWB tag                  |
|                     +                              |
|                                                    |
|                                                    |
Anchor 1 (0, 0)      -------- Anchor 4 (X_max, 0)
```

- **Anchor 1**: Fixed at origin (0,0) - reference point
- **Anchor 2**: Positive Y direction  
- **Anchor 3**: Positive X and Y direction
- **Anchor 4**: Positive X direction
- **Robot tag**: Provides position relative to anchors

## Topics

### Input Topics
- `/fused_xy_uwb` (geometry_msgs/Point): Robot X,Y position from UWB fusion
- `/imu_1_yaw` (std_msgs/Float64): Robot yaw angle from IMU
- `/scan` (sensor_msgs/LaserScan): LiDAR scan data

### Output Topics
- `/map` (nav_msgs/OccupancyGrid): Generated occupancy grid map
- TF transforms: `map -> base_link -> laser_frame`

## Usage

### 1. Basic Launch
```bash
ros2 launch Forklift_Firmware uwb_slam_system.launch.py
```

### 2. Launch with Custom Parameters
```bash
ros2 launch Forklift_Firmware uwb_slam_system.launch.py \
    map_resolution:=0.1 \
    map_size:=1000 \
    max_range:=10.0 \
    yaw_offset:=90.0
```

### 3. Launch Parameters

| Parameter | Default | Description |
|---|---|---|
| `map_resolution` | 0.05 | Map resolution in meters per pixel |
| `map_size` | 2000 | Map size in pixels (width × height) |
| `max_range` | 12.0 | Maximum laser range to consider (meters) |
| `yaw_offset` | 0.0 | IMU yaw calibration offset (degrees) |

## Configuration

### UWB Transform Publisher Parameters
```yaml
uwb_imu_transform_publisher:
  z_position: 0.0          # Robot height above ground
  publish_frequency: 50.0   # Transform publishing rate (Hz)
  anchor_1_x: 0.0          # Anchor 1 X coordinate (reference)
  anchor_1_y: 0.0          # Anchor 1 Y coordinate (reference)
  yaw_offset: 0.0          # IMU yaw offset in degrees
```

### SLAM Parameters
```yaml
uwb_static_slam:
  map_resolution: 0.05      # Meters per pixel
  map_width: 2000          # Map width in pixels
  map_height: 2000         # Map height in pixels
  update_frequency: 10.0    # Map update rate (Hz)
  occupied_threshold: 0.65  # Occupied cell probability threshold
  free_threshold: 0.35     # Free cell probability threshold
  log_odds_occupied: 0.4   # Log odds increment for occupied
  log_odds_free: 0.2       # Log odds decrement for free
  max_range: 12.0          # Maximum laser range (meters)
```

## Coordinate Systems

### Map Frame
- **Origin**: Anchor 1 position (0, 0)
- **X-axis**: Towards Anchor 4 (positive X)
- **Y-axis**: Towards Anchor 2 (positive Y)
- **Z-axis**: Up (right-hand rule)

### Robot Frame
- **base_link**: Robot center, aligned with map frame
- **laser_frame**: LiDAR sensor frame, child of base_link

## Calibration

### IMU Yaw Calibration
1. Place robot facing from Anchor 1 towards Anchor 2
2. Check IMU yaw reading
3. Set `yaw_offset` parameter to make yaw = 0°

### UWB Position Calibration
1. Ensure Anchor 1 coordinates are set to (0, 0)
2. Verify other anchors form a proper rectangle
3. Check robot position readings match physical location

## Troubleshooting

### No Map Generated
- Check if `/scan` topic is publishing
- Verify transforms are being published: `ros2 run tf2_tools view_frames.py`
- Ensure UWB and IMU data are being received

### Incorrect Robot Position
- Verify UWB anchor positions
- Check `yaw_offset` parameter
- Confirm `/fused_xy_uwb` topic data format

### Poor Map Quality
- Adjust `map_resolution` for finer detail
- Tune `occupied_threshold` and `free_threshold`
- Increase `max_range` if needed
- Check laser scan quality

### Transform Errors
- Ensure all topics are publishing at reasonable rates
- Check topic names match your system
- Verify message types are correct

## Visualization

The system launches RViz2 with preconfigured visualization showing:
- Occupancy grid map
- Laser scan data
- Robot position and orientation
- TF frame tree

## File Structure

```
src/Forklift_Firmware/
├── src/
│   ├── uwb_imu_transform_publisher.py  # UWB+IMU → TF transforms
│   └── uwb_static_slam.py              # SLAM mapping node
├── launch/
│   └── uwb_slam_system.launch.py       # Main launch file
├── rviz/
│   └── uwb_slam.rviz                   # RViz configuration
└── README_UWB_SLAM.md                  # This file
```

## Dependencies

- ROS 2 Humble
- Python 3
- NumPy
- tf2_ros
- sensor_msgs
- nav_msgs
- geometry_msgs
- std_msgs

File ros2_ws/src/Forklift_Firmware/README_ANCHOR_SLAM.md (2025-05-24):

# Anchor-Based SLAM System

## Overview

This system implements SLAM using a fixed anchor-based coordinate system where Anchor 1 serves as the origin of the map frame. The robot moves within this fixed coordinate system, providing consistent localization relative to the physical anchor layout.

## Coordinate System

### Anchor Layout
```
A2(0,170) ---- A3(200,170)
|                       |
|        Robot          |
|                       |
A1(0,0)   ---- A4(200,0)
```

All coordinates are in centimeters in the UWB system, converted to meters for ROS.

### Reference Frame
- **Map Origin**: Anchor 1 at (0,0)
- **X-axis**: Points from Anchor 1 towards Anchor 4 (East)
- **Y-axis**: Points from Anchor 1 towards Anchor 2 (North)
- **Z-axis**: Points upward (standard ROS convention)

### Orientation Convention
- **0°**: Robot facing North (from Anchor 1 towards Anchor 2)
- **90°**: Robot facing East (from Anchor 1 towards Anchor 4)
- **180°**: Robot facing South (from Anchor 2 towards Anchor 1)
- **270°**: Robot facing West (from Anchor 4 towards Anchor 1)

## Key Files

### `dynamic_uwb_positioning.py`
- Subscribes to `/uwb_fused_xy` for position data
- Subscribes to `/imu_1_yaw` for orientation data
- Publishes `map -> laser_frame` transform
- Maintains fixed map frame with Anchor 1 as origin
- Applies 85° counter-clockwise rotation to align laser frame with yaw angle

### `uwb_imu_fusion.py`
- Fuses UWB distance measurements with IMU data
- Publishes fused position to `/uwb_fused_xy`
- Uses orientation-weighted trilateration for improved accuracy

### `test_uwb_imu_publisher.py`
- Simulates UWB and IMU data for testing
- Generates circular motion within anchor area
- Useful for testing without physical hardware

## Launch Files

### Production Use
```bash
ros2 launch rplidar_ros anchor_based_slam.launch.py
```
- Uses real UWB/IMU fusion
- Requires physical UWB anchors and IMU
- Includes system health monitoring

### Testing
```bash
ros2 launch rplidar_ros test_anchor_slam.launch.py
```
- Uses simulated UWB/IMU data
- Good for development and testing
- No physical hardware required

## Topics

### Input Topics
- `/uwb_raw_distances` (Float32MultiArray): Raw UWB distances to anchors
- `/imu_1_yaw` (Float64): IMU yaw angle in degrees or radians
- `/scan` (LaserScan): LiDAR scan data

### Output Topics
- `/uwb_fused_xy` (Point): Fused position in anchor coordinates (cm)
- `/map` (OccupancyGrid): SLAM-generated map
- `/tf` (TF2): Transform tree including map->laser_frame

## System Requirements

1. **UWB Anchors**: Must be positioned exactly as specified in anchor layout
2. **IMU**: Must provide yaw angle aligned with coordinate system
3. **LiDAR**: Compatible with rplidar_ros package

## Calibration

### IMU Alignment
If IMU yaw doesn't align with the coordinate system:
1. Modify `yaw_callback()` in `dynamic_uwb_positioning.py`
2. Add offset: `self.map_yaw = imu_yaw_rad + your_offset`

### Laser Frame Alignment
The laser frame is automatically rotated 85° counter-clockwise from the IMU yaw to align with the physical laser orientation. If this needs adjustment:
1. Modify `self.laser_rotation_offset` in `dynamic_uwb_positioning.py`
2. Value is in radians (current: 85° = 1.484 radians)

### Anchor Position Verification
Verify anchor positions match the layout in `uwb_imu_fusion.py`:
```python
self.anchor1 = np.array([0, 0])      # A1
self.anchor2 = np.array([0, 170])    # A2  
self.anchor3 = np.array([200, 170])  # A3
self.anchor4 = np.array([200, 0])    # A4 (virtual reference)
```

## Troubleshooting

### No Position Updates
- Check `/uwb_fused_xy` topic: `ros2 topic echo /uwb_fused_xy`
- Check `/imu_1_yaw` topic: `ros2 topic echo /imu_1_yaw`
- Verify anchor positions and UWB signal quality

### Map Not Fixed
- Ensure `dynamic_uwb_positioning.py` is running
- Check TF tree: `ros2 run tf2_tools view_frames`
- Verify map->laser_frame transform is being published

### Laser Scan Misalignment
- Verify the 85° laser rotation offset is correct for your hardware
- Check that laser data aligns with robot movement in RViz
- Adjust `laser_rotation_offset` if needed

### Poor Localization
- Check UWB distance measurements for consistency
- Verify IMU calibration and orientation alignment
- Ensure anchors are positioned as specified

## Monitoring

Use the fusion tester to monitor system health:
```bash
ros2 run Forklift_Firmware uwb_fusion_test.py
```

This provides real-time status of:
- UWB distance measurements
- IMU data
- Position fusion quality
- Update rates

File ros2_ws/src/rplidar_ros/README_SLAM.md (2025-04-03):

# Real-time SLAM for RPLidar

This package provides a real-time SLAM (Simultaneous Localization and Mapping) implementation for a stationary RPLidar sensor. It creates a 2D occupancy grid map of the environment based on the laser scan data and continuously updates it to track moving objects.

## Overview

The real-time SLAM implementation is designed for scenarios where the lidar sensor is fixed in place but objects in the environment may be moving. It builds and continuously updates a map by:

1. Processing laser scan data from the RPLidar
2. Converting range and angle measurements to Cartesian coordinates
3. Marking occupied cells at the endpoints of laser beams
4. Marking free space along the beam path using Bresenham's line algorithm
5. Applying a decay factor to gradually forget old observations
6. Updating an occupancy grid map using a probabilistic approach
7. Publishing the map for visualization in RViz

## Key Features

- **Real-time mapping**: The map continuously updates to reflect changes in the environment
- **Moving object tracking**: Objects that move will be updated in the map
- **Decay mechanism**: Old observations gradually fade away, allowing the map to adapt to changes
- **Consistency weighting**: Consistent observations across multiple scans are weighted more heavily
- **Stationary lidar**: Optimized for a fixed lidar setup

## Prerequisites

- ROS 2 (tested with Foxy/Galactic/Humble)
- RPLidar ROS 2 package (this repository)
- Python 3 with NumPy
- Matplotlib (for map visualization)

## Usage

### 1. Build the package

```bash
cd ~/ros2_ws/
colcon build --packages-select rplidar_ros
source install/setup.bash
```

### 2. Quick Start (All-in-One)

For convenience, you can use the provided shell script to run the entire SLAM process and save the map in one command:

```bash
./scripts/run_slam_and_save.sh
```

This script will:
1. Start the RPLidar driver and SLAM node
2. Run the mapping process until you press Ctrl+C
3. Automatically save the map when you stop the process

### 3. Manual Process

If you prefer to run each step manually, follow these instructions:

#### 3.1 Launch the SLAM node

```bash
ros2 launch rplidar_ros static_slam.launch.py
```

This will:
- Start the RPLidar driver
- Launch the SLAM node
- Open RViz with a configuration for visualizing the map

#### 3.2 Visualizing the Map

The map is published on the `/map` topic as a `nav_msgs/OccupancyGrid` message. In RViz:
- The map is displayed with the standard color scheme:
  - Black: Occupied cells (100)
  - White: Free cells (0)
  - Gray: Unknown cells (-1)
- The laser scan data is shown in red
- The coordinate frames (map and laser_frame) are visualized
- **The map will continuously update as objects move in the environment**

#### 3.3 Saving the Map

Once you're satisfied with the generated map, you can save it to disk using the provided map saver utility:

```bash
ros2 run rplidar_ros save_map.py
```

This will:
- Subscribe to the `/map` topic
- Save the map in multiple formats:
  - `.npy`: NumPy binary format for further processing
  - `.pgm`: Portable Gray Map format compatible with ROS map_server
  - `.yaml`: YAML metadata file for use with ROS navigation stack
- Create a timestamped filename to avoid overwriting previous maps
- Store maps in the `~/ros2_ws/maps/` directory

The saved map can be used later for navigation or other applications.

### 4. Viewing Saved Maps

You can view saved maps using the provided visualization tool:

```bash
# List all available maps
python3 scripts/view_map.py --list

# View a specific map by index
python3 scripts/view_map.py --list --index 1

# View a specific map file
python3 scripts/view_map.py --map ~/ros2_ws/maps/map_20230101_120000.npy

# Interactive mode (lists maps and prompts for selection)
python3 scripts/view_map.py
```

This tool uses Matplotlib to display the map with the proper color scheme for occupied, free, and unknown cells.

## Parameters

You can adjust the following parameters in the `static_slam.py` file to tune the real-time mapping behavior:

- `map_resolution`: Resolution of the map in meters per pixel (default: 0.05)
- `map_width` and `map_height`: Size of the map in pixels (default: 1000x1000)
- `decay_factor`: How quickly to forget old observations (default: 0.05)
- `recent_scans_weight`: Weight for consistent observations across scans (default: 2.0)
- `scan_buffer_size`: Number of recent scans to keep for comparison (default: 3)
- Probability thresholds for occupied/free space classification

## How the Real-time Mapping Works

1. **Decay Mechanism**: A small decay factor is applied to the entire map on each update, gradually moving all cells toward the prior probability. This allows the map to "forget" old observations.

2. **Consistency Tracking**: The system keeps a buffer of recent scans and compares new observations with previous ones. Consistent observations (points that appear in the same place across multiple scans) are weighted more heavily.

3. **Continuous Updates**: Unlike traditional SLAM that might stop updating after a fixed number of scans, this implementation continues to update indefinitely, allowing it to track moving objects.

## Limitations

- This implementation is designed for a stationary lidar and does not handle sensor movement
- The map size is fixed and predefined
- Very fast-moving objects might appear blurred or leave "trails" in the map
- The implementation uses a simple log-odds approach for occupancy grid mapping

## Troubleshooting

- If the map appears empty, check that the lidar is publishing data on the `/scan` topic
- If the map is not updating, ensure the transform between `map` and `laser_frame` is being published correctly
- Adjust the map size and resolution if the environment is too large or too detailed for the current settings
- If moving objects leave too much of a "trail", increase the `decay_factor` parameter
- If the map changes too quickly, decrease the `decay_factor` parameter

## License

This package is licensed under the same terms as the RPLidar ROS package.

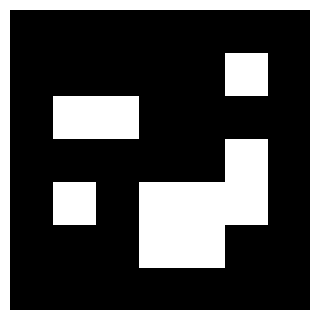
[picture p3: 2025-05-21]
aruco/aruco_marker_1.png

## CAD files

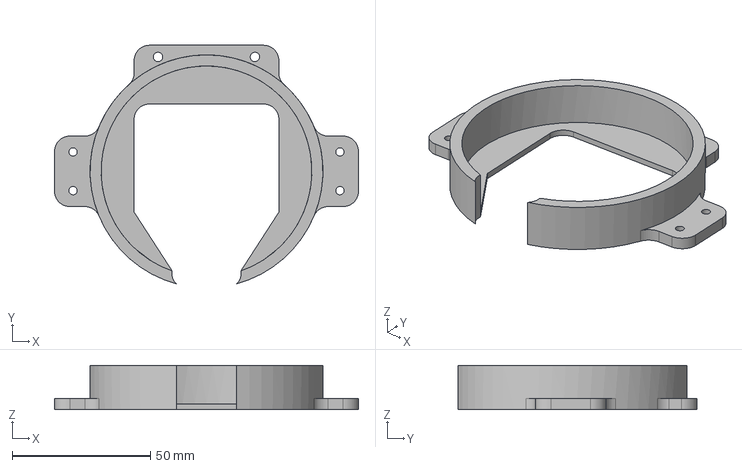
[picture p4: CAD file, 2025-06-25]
bot_design/STEP/RP_Lidar_A2M8_Mount.step
109.9 x 86.3 x 16.0 mm

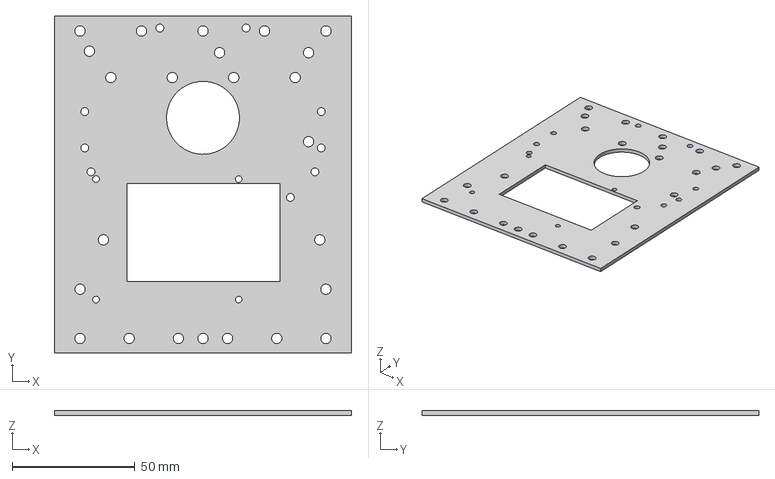
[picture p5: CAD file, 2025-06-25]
bot_design/STEP/small_chassis.step
120.8 x 137.0 x 2.00 mm

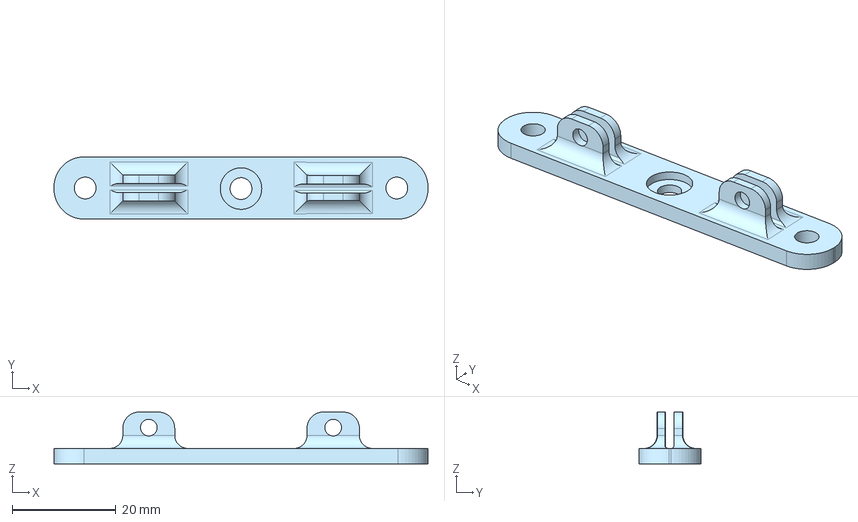
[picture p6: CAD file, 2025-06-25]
bot_design/STEP/UWB_Mount_v2_without_battery.step
72.0 x 12.0 x 10.0 mm

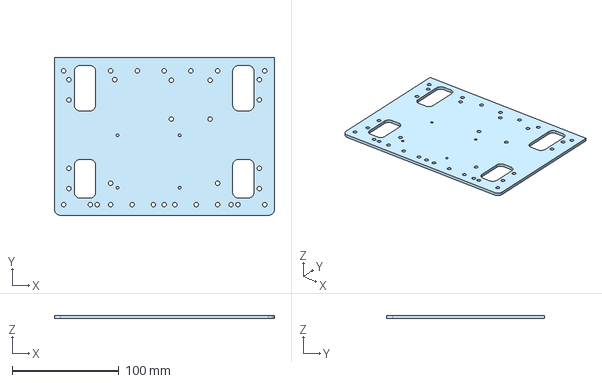
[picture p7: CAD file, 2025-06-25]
bot_design/STEP/large chassis.step
205.6 x 147.3 x 3.00 mm

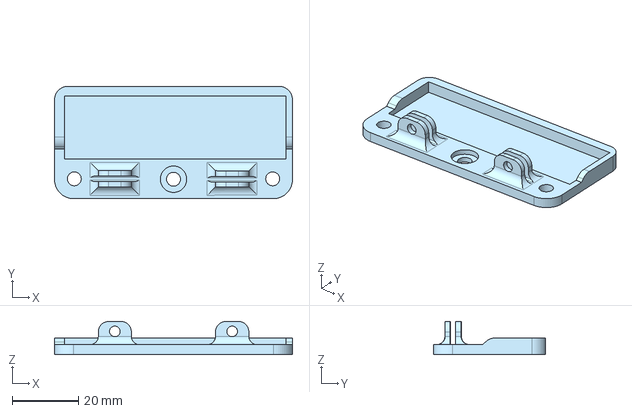
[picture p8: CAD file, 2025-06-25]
bot_design/STEP/UWB_Mount_v2.step
72.0 x 34.0 x 10.0 mm

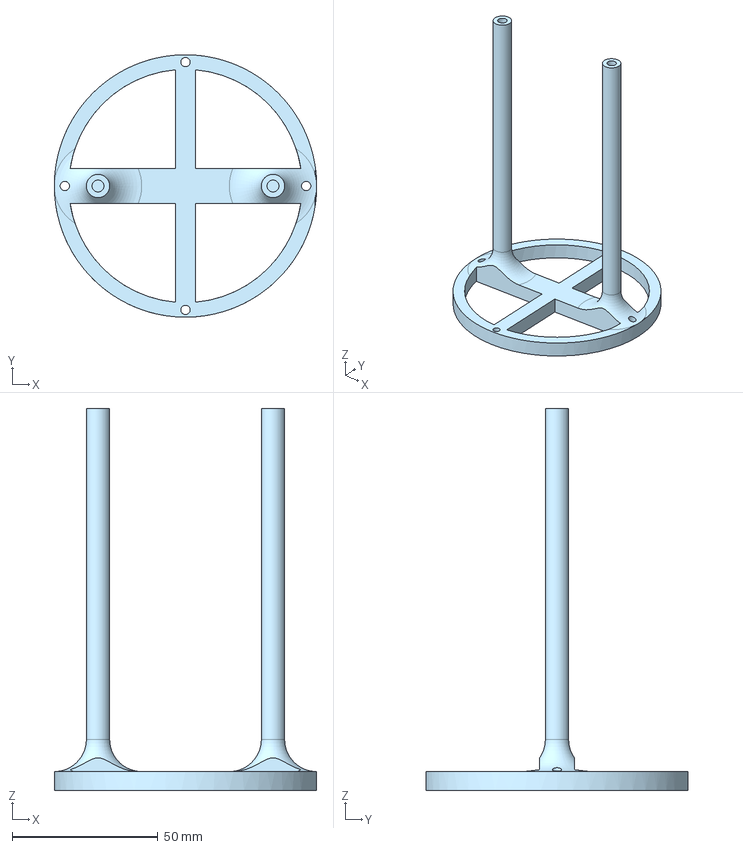
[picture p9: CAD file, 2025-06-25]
bot_design/STEP/UWB_anchor_stand_13cm.step
90.0 x 90.0 x 131.0 mm

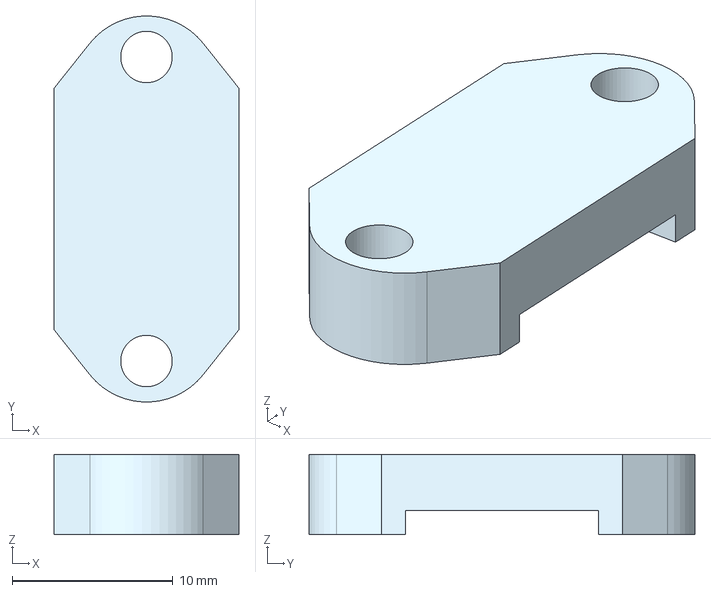
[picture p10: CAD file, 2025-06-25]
bot_design/STEP/N20_Motor_Mount_Upper.step
11.5 x 24.0 x 5.00 mm

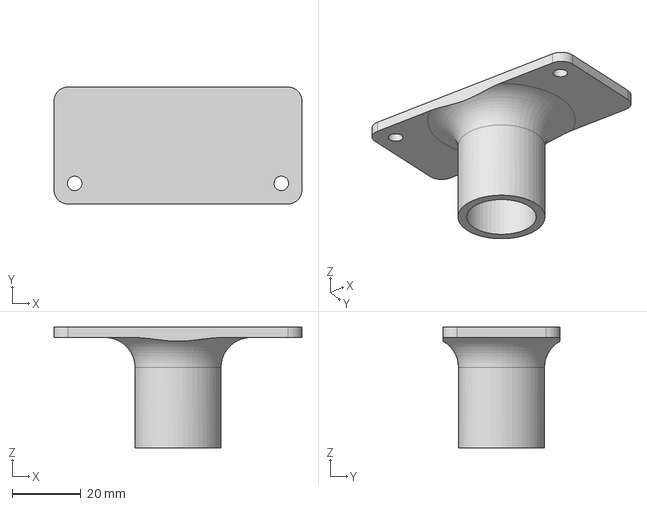
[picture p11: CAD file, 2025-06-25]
bot_design/STEP/UWB_Mount_PVC_Connector_v1.step
72.0 x 34.0 x 35.0 mm

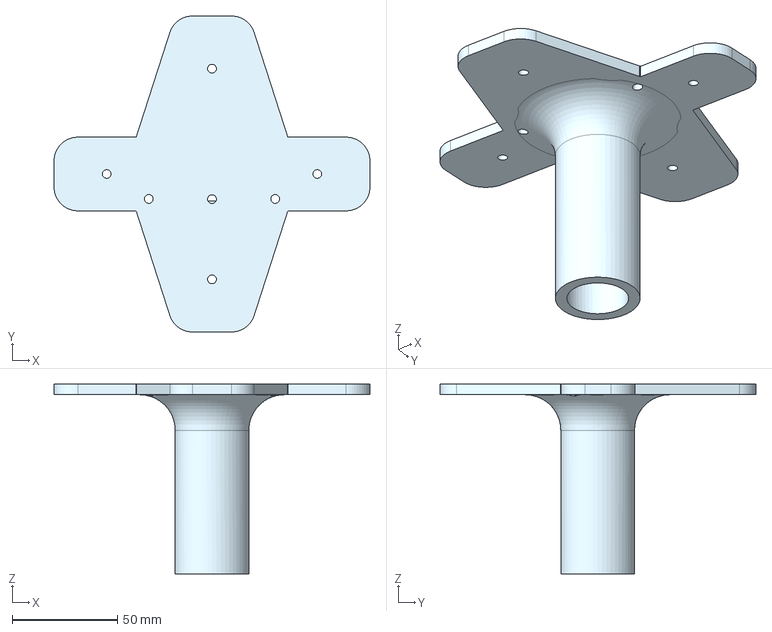
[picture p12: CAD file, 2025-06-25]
bot_design/STEP/PVC_Pipe_25mm_Stand.step
150.0 x 150.0 x 90.0 mm

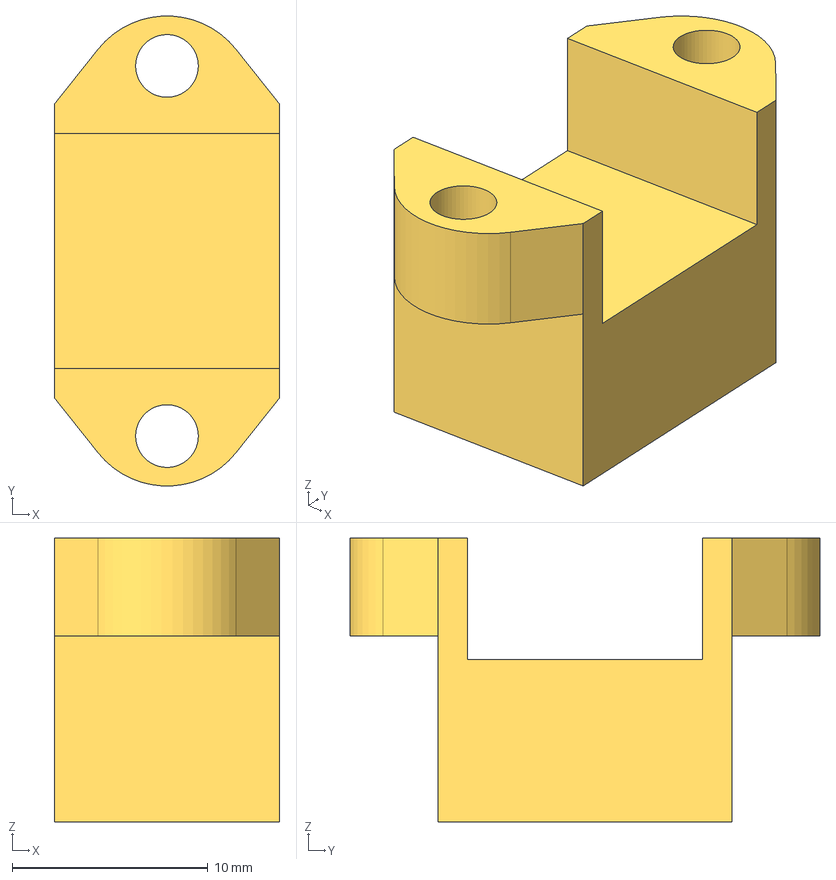
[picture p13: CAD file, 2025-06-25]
bot_design/STEP/N20_Motor_Mount_Lower.step
11.5 x 24.0 x 14.5 mm

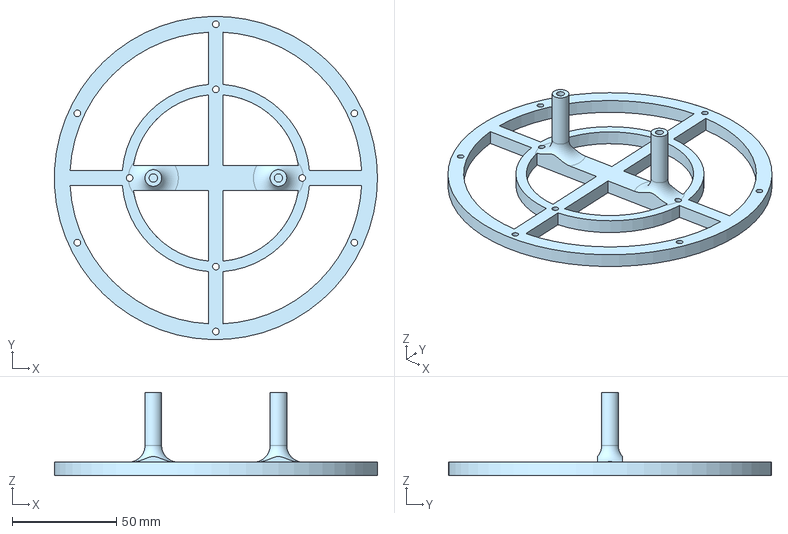
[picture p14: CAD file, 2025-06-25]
bot_design/STEP/UWB_Tag_Accuracy_Check.step
154.9 x 154.9 x 40.0 mm

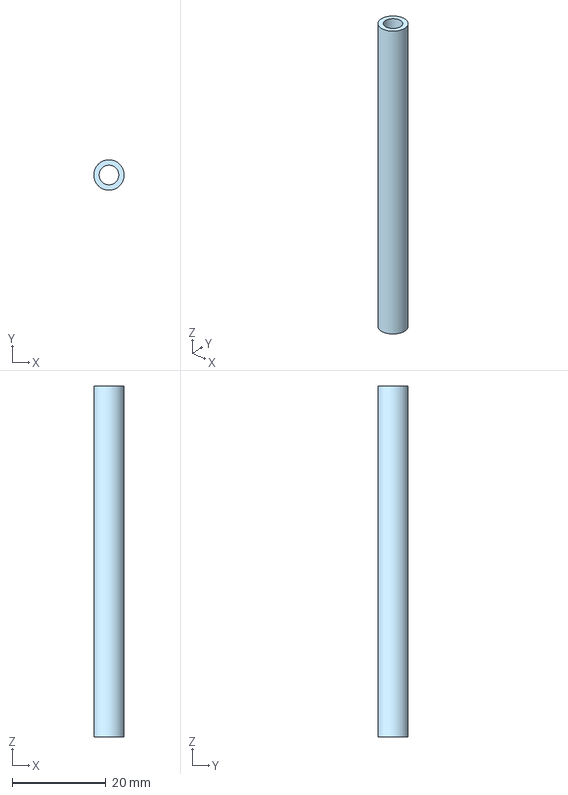
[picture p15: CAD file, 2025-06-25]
bot_design/STEP/4mm-screw_spacer_OD-6.5mm_ID-4.2mm_75mm.step
6.49 x 6.50 x 75.0 mm

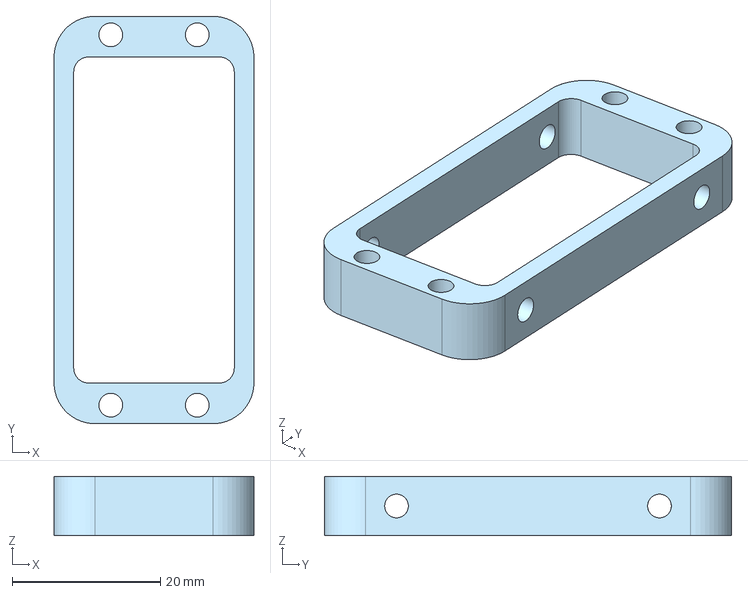
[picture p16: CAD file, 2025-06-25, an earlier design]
bot_design/STEP/UWB_Mount_V1.step
27.0 x 55.0 x 8.00 mm

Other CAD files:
bot_design/STL/4mm-screw_spacer_OD-6.5mm_ID-4.2mm_75mm.stl
bot_design/STL/N20_Motor_Mount_Lower.stl
bot_design/STL/N20_Motor_Mount_Upper.stl
bot_design/STL/PVC_Pipe_25mm_Stand.stl
bot_design/STL/RP_Lidar_A2M8_Mount.stl
bot_design/STL/UWB_Mount_PVC_Connector_v1.stl
bot_design/STL/UWB_Mount_v1.stl
bot_design/STL/UWB_Mount_v2.stl
bot_design/STL/UWB_Mount_v2_without_battery.stl
bot_design/STL/UWB_Tag_Accuracy_Check.stl
bot_design/STL/UWB_anchor_stand_13cm.stl
bot_design/STL/large_chassis.stl
bot_design/STL/small_chassis.stl

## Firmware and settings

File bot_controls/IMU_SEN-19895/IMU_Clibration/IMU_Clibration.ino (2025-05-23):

/*
  9DoF IMU Yaw Reading with Calibration and Diagnostics
  Fixed test rotation function + improved for Kalman filter readiness
  
  Hardware: SEN-19895 9DoF IMU Sensor
*/

#include <Wire.h>
#include <SparkFun_ISM330DHCX.h>
#include <SparkFun_MMC5983MA_Arduino_Library.h>

SparkFun_ISM330DHCX myISM;
SFE_MMC5983MA myMag;

// Sensor data structures
sfe_ism_data_t gyroData;
uint32_t rawMagX, rawMagY, rawMagZ;

// Yaw calculation variables
float magneticYaw = 0.0;
float gyroYaw = 0.0;
float fusedYaw = 0.0;

// Timing variables
unsigned long lastTime = 0;
float deltaTime = 0.0;

// Complementary filter coefficient
float alpha = 0.95;

// Magnetometer calibration parameters
float magOffsetX = 0.0;
float magOffsetY = 0.0;
float magScaleX = 1.0;
float magScaleY = 1.0;
bool magCalibrated = false;

// Yaw correction parameters
float yawCorrectionFactor = 0.96;
float yawOffsetCorrection = 0.0;

// Gyroscope parameters
float gyroBiasZ = 0.0;
float gyroFilteredZ = 0.0;
bool biasCalculated = false;

// Kalman filter variables (for future implementation)
float Q_angle = 0.001;  // Process noise covariance for angle
float Q_gyro = 0.003;   // Process noise covariance for gyro bias
float R_measure = 0.03; // Measurement noise covariance
float P[2][2] = {{1, 0}, {0, 1}}; // Error covariance matrix
float K[2]; // Kalman gain
float y, S; // Innovation and innovation covariance
float kalmanYaw = 0.0;
float gyroBias = 0.0;

// Calibration mode flag
bool calibrationMode = false;
bool useKalmanFilter = false;

void setup() {
    Serial.begin(115200);
    Serial.println("9DoF IMU Yaw Estimation with Advanced Filtering");
    Serial.println("===============================================");
    
    Wire.begin();
    Wire.setClock(400000);
    
    // Initialize sensors
    if (!initializeSensors()) {
        Serial.println("Sensor initialization failed!");
        while (true);
    }
    
    Serial.println("Sensors initialized successfully!");
    showMenu();
}

void loop() {
    // Check for serial commands
    if (Serial.available()) {
        handleSerialCommand();
        return;
    }
    
    // Normal operation - read and display yaw
    if (!calibrationMode) {
        updateYawReadings();
        displayYawData();
        delay(100); // 10Hz update rate for display
    }
}

bool initializeSensors() {
    // Initialize ISM330DHCX
    if (!myISM.begin()) {
        Serial.println("ISM330DHCX not found!");
        return false;
    }
    
    myISM.deviceReset();
    while (!myISM.getDeviceReset()) delay(1);
    
    myISM.setDeviceConfig();
    myISM.setBlockDataUpdate();
    myISM.setGyroDataRate(ISM_GY_ODR_208Hz);
    myISM.setGyroFullScale(ISM_250dps);
    myISM.setGyroFilterLP1();
    myISM.setGyroLP1Bandwidth(ISM_MEDIUM);
    
    // Initialize MMC5983MA
    if (!myMag.begin()) {
        Serial.println("MMC5983MA not found!");
        return false;
    }
    
    myMag.softReset();
    myMag.setFilterBandwidth(100);
    myMag.enableAutomaticSetReset();
    
    return true;
}

void showMenu() {
    Serial.println("\nCommands:");
    Serial.println("  'c' - Calibrate magnetometer");
    Serial.println("  'g' - Calibrate gyroscope bias");
    Serial.println("  'r' - Show raw magnetometer values");
    Serial.println("  's' - Start yaw readings");
    Serial.println("  't' - Test rotation (place at 0°, 90°, 180°, 270°)");
    Serial.println("  'a' - Apply correction based on test results");
    Serial.println("  'k' - Toggle Kalman filter (currently " + String(useKalmanFilter ? "ON" : "OFF") + ")");
    Serial.println("  'd' - Debug mode (detailed magnetometer analysis)");
    Serial.println("  'm' - Show this menu");
}

void displayYawData() {
    Serial.print("Mag: ");
    Serial.print(magneticYaw, 1);
    Serial.print("° | Gyro: ");
    Serial.print(gyroYaw, 1);
    Serial.print("°");
    
    if (useKalmanFilter) {
        Serial.print(" | Kalman: ");
        Serial.print(kalmanYaw, 1);
        Serial.print("°");
    }
    
    Serial.print(" | Fused: ");
    Serial.print(fusedYaw, 1);
    Serial.println("°");
}

void handleSerialCommand() {
    char command = Serial.read();
    
    // Clear any remaining characters in buffer
    while (Serial.available()) {
        Serial.read();
        delay(1);
    }
    
    switch (command) {
        case 'c':
            calibrateMagnetometer();
            break;
        case 'g':
            calibrateGyroBias();
            break;
        case 'r':
            showRawMagValues();
            break;
        case 's':
            startYawReadings();
            break;
        case 't':
            testRotation();
            break;
        case 'a':
            applyTestCorrection();
            break;
        case 'k':
            toggleKalmanFilter();
            break;
        case 'd':
            debugMagnetometer();
            break;
        case 'm':
            showMenu();
            break;
    }
}

void toggleKalmanFilter() {
    useKalmanFilter = !useKalmanFilter;
    Serial.println("\nKalman filter " + String(useKalmanFilter ? "ENABLED" : "DISABLED"));
    
    if (useKalmanFilter) {
        // Initialize Kalman filter
        kalmanYaw = magneticYaw;
        gyroBias = gyroBiasZ;
        P[0][0] = 1.0;
        P[0][1] = 0.0;
        P[1][0] = 0.0;
        P[1][1] = 1.0;
        Serial.println("Kalman filter initialized with current magnetic heading");
    }
    Serial.println();
}

void calibrateMagnetometer() {
    Serial.println("\n=== MAGNETOMETER CALIBRATION ===");
    Serial.println("Slowly rotate the sensor in ALL directions for 30 seconds.");
    Serial.println("Make complete rotations around all axes (X, Y, Z).");
    Serial.println("Starting in 3 seconds...");
    delay(3000);
    
    float minX = 999999, maxX = -999999;
    float minY = 999999, maxY = -999999;
    
    unsigned long startTime = millis();
    int sampleCount = 0;
    
    Serial.println("Calibrating... (rotate sensor now!)");
    
    while (millis() - startTime < 30000) {
        myMag.getMeasurementXYZ(&rawMagX, &rawMagY, &rawMagZ);
        
        float x = (float)rawMagX - 131072.0;
        float y = (float)rawMagY - 131072.0;
        
        if (x < minX) minX = x;
        if (x > maxX) maxX = x;
        if (y < minY) minY = y;
        if (y > maxY) maxY = y;
        
        sampleCount++;
        
        if (sampleCount % 100 == 0) {
            Serial.print(".");
        }
        
        delay(10);
    }
    
    // Calculate calibration parameters
    magOffsetX = (maxX + minX) / 2.0;
    magOffsetY = (maxY + minY) / 2.0;
    
    float rangeX = (maxX - minX) / 2.0;
    float rangeY = (maxY - minY) / 2.0;
    float avgRange = (rangeX + rangeY) / 2.0;
    
    magScaleX = avgRange / rangeX;
    magScaleY = avgRange / rangeY;
    
    magCalibrated = true;
    
    Serial.println("\nCalibration complete!");
    Serial.println("Calibration parameters:");
    Serial.print("  Offset X: "); Serial.println(magOffsetX, 1);
    Serial.print("  Offset Y: "); Serial.println(magOffsetY, 1);
    Serial.print("  Scale X:  "); Serial.println(magScaleX, 3);
    Serial.print("  Scale Y:  "); Serial.println(magScaleY, 3);
    Serial.print("  Samples:  "); Serial.println(sampleCount);
    Serial.println();
}

void calibrateGyroBias() {
    Serial.println("\n=== GYROSCOPE BIAS CALIBRATION ===");
    Serial.println("Keep sensor COMPLETELY still for 5 seconds...");
    delay(2000);
    
    float biasSum = 0.0;
    int samples = 0;
    unsigned long startTime = millis();
    
    while (millis() - startTime < 5000) {
        if (myISM.checkGyroStatus()) {
            myISM.getGyro(&gyroData);
            biasSum += gyroData.zData;
            samples++;
        }
        delay(5);
    }
    
    if (samples > 0) {
        gyroBiasZ = biasSum / samples;
        biasCalculated = true;
        
        Serial.println("Gyro bias calibration complete:");
        Serial.print("  Bias Z: "); Serial.print(gyroBiasZ, 2); Serial.println(" °/s");
        Serial.print("  Samples: "); Serial.println(samples);
        
        if (abs(gyroBiasZ) > 200) {
            Serial.println("  WARNING: Large bias detected - sensor may not have been still!");
        }
    }
    Serial.println();
}

void testRotation() {
    if (!magCalibrated) {
        Serial.println("Please calibrate magnetometer first (command 'c')");
        return;
    }
    
    Serial.println("\n=== ROTATION TEST ===");
    Serial.println("This will test clockwise rotations of 90 degrees each.");
    Serial.println("Place sensor at each position and press ENTER:");
    
    float testReadings[4];
    String positions[] = {"0°", "90°", "180°", "270°"};
    
    for (int i = 0; i < 4; i++) {
        Serial.print("Position sensor at "); Serial.print(positions[i]); 
        Serial.print(" and press ENTER... ");
        
        // Wait for Enter key specifically
        waitForEnter();
        
        // Take multiple readings and average for stability
        float sum = 0;
        for (int j = 0; j < 10; j++) {  // More samples for better accuracy
            updateMagneticYaw();
            sum += magneticYaw;
            delay(50);
        }
        testReadings[i] = sum / 10.0;
        
        Serial.print("Reading: "); Serial.println(testReadings[i], 1);
    }
    
    Serial.println("\n=== ROTATION TEST RESULTS ===");
    for (int i = 0; i < 4; i++) {
        Serial.print(positions[i]); Serial.print(": "); Serial.println(testReadings[i], 1);
    }
    
    // Calculate differences with proper angle wrapping
    Serial.println("\nClockwise angular differences (should be ~90°):");
    float totalError = 0;
    int validMeasurements = 0;
    
    for (int i = 0; i < 4; i++) {
        int nextIndex = (i + 1) % 4;  // Wrap around for 270° to 0°
        
        float diff = testReadings[nextIndex] - testReadings[i];
        
        // Handle angle wrapping properly for clockwise rotation
        if (diff < -180.0) diff += 360.0;  // Cross 0° boundary
        if (diff > 180.0) diff -= 360.0;   // Should not happen for 90° rotations
        
        // For clockwise rotation, difference should be positive ~90°
        // If negative, we crossed the 0° boundary
        if (diff < 0 && i == 3) {  // 270° to 0° transition
            diff = (360.0 - testReadings[i]) + testReadings[nextIndex];
        }
        
        float error = abs(90.0 - abs(diff));
        totalError += error;
        validMeasurements++;
        
        Serial.print(positions[i]); Serial.print(" to "); Serial.print(positions[nextIndex]); 
        Serial.print(": "); Serial.print(diff, 1); 
        Serial.print("° (error: "); Serial.print(error, 1); Serial.println("°)");
    }
    
    if (validMeasurements > 0) {
        float avgError = totalError / validMeasurements;
        Serial.print("\nAverage error: "); Serial.print(avgError, 1); Serial.println("°");
        
        if (avgError > 5.0) {
            Serial.println("Large errors detected. Possible issues:");
            Serial.println("- Magnetometer needs recalibration");
            Serial.println("- Magnetic interference present");
            Serial.println("- Correction factor needed (command 'a')");
        } else {
            Serial.println("Good accuracy! Readings are within acceptable range.");
        }
    }
    Serial.println();
}

void waitForEnter() {
    // Clear any existing input
    while (Serial.available()) {
        Serial.read();
        delay(1);
    }
    
    // Wait for Enter key (newline character)
    while (true) {
        if (Serial.available()) {
            char c = Serial.read();
            if (c == '\n' || c == '\r') {
                break;
            }
        }
        // Continue updating readings while waiting
        updateMagneticYaw();
        delay(10);
    }
    
    // Clear any remaining characters
    while (Serial.available()) {
        Serial.read();
        delay(1);
    }
}

void applyTestCorrection() {
    Serial.println("\n=== APPLY TEST-BASED CORRECTION ===");
    Serial.println("Current correction factor: " + String(yawCorrectionFactor, 3));
    Serial.println("Current offset correction: " + String(yawOffsetCorrection, 1));
    Serial.println();
    Serial.println("Based on typical test results:");
    Serial.println("Recommended correction factor: 0.96 (reduces ~4% over-rotation)");
    Serial.println();
    Serial.print("Apply recommended correction? (y/n): ");
    
    while (!Serial.available()) delay(10);
    char response = Serial.read();
    Serial.println(response);
    
    if (response == 'y' || response == 'Y') {
        yawCorrectionFactor = 0.96;
        yawOffsetCorrection = 0.0;
        Serial.println("Correction applied! Test rotation again to verify improvement.");
    } else {
        Serial.println("Correction not applied.");
    }
    Serial.println();
}

void showRawMagValues() {
    Serial.println("\n=== RAW MAGNETOMETER VALUES ===");
    Serial.println("Format: X, Y, Z (raw) | X, Y (calibrated)");
    Serial.println("Press any key to stop...");
    
    while (!Serial.available()) {
        myMag.getMeasurementXYZ(&rawMagX, &rawMagY, &rawMagZ);
        
        float rawX = (float)rawMagX - 131072.0;
        float rawY = (float)rawMagY - 131072.0;
        float rawZ = (float)rawMagZ - 131072.0;
        
        float calX = (rawX - magOffsetX) * magScaleX;
        float calY = (rawY - magOffsetY) * magScaleY;
        
        Serial.print(rawX, 0); Serial.print(", ");
        Serial.print(rawY, 0); Serial.print(", ");
        Serial.print(rawZ, 0); Serial.print(" | ");
        Serial.print(calX, 1); Serial.print(", ");
        Serial.println(calY, 1);
        
        delay(200);
    }
    Serial.read();
    Serial.println();
}

void startYawReadings() {
    if (!magCalibrated) {
        Serial.println("Please calibrate magnetometer first (command 'c')");
        return;
    }
    
    Serial.println("\n=== YAW READINGS ===");
    if (useKalmanFilter) {
        Serial.println("Format: Magnetic | Gyro | Kalman | Fused");
    } else {
        Serial.println("Format: Magnetic | Gyro | Fused");
    }
    Serial.println("Press any key to stop...");
    
    lastTime = millis();
    gyroYaw = magneticYaw;
    
    if (useKalmanFilter) {
        kalmanYaw = magneticYaw;
    }
    
    while (!Serial.available()) {
        updateYawReadings();
        displayYawData();
        delay(100);
    }
    Serial.read();
    Serial.println();
}

void updateYawReadings() {
    unsigned long currentTime = millis();
    deltaTime = (currentTime - lastTime) / 1000.0;
    
    if (deltaTime >= 0.01) {
        updateMagneticYaw();
        updateGyroYaw();
        
        if (useKalmanFilter) {
            updateKalmanFilter();
        }
        
        fuseYawEstimates();
        lastTime = currentTime;
    }
}

void updateMagneticYaw() {
    myMag.getMeasurementXYZ(&rawMagX, &rawMagY, &rawMagZ);
    
    // Apply calibration
    float calX = ((float)rawMagX - 131072.0 - magOffsetX) * magScaleX;
    float calY = ((float)rawMagY - 131072.0 - magOffsetY) * magScaleY;
    
    // Normalize to unit vector
    float magnitude = sqrt(calX * calX + calY * calY);
    if (magnitude > 0) {
        calX /= magnitude;
        calY /= magnitude;
    }
    
    // Calculate heading (atan2 returns -π to π, convert to 0-360)
    // Note: Check your sensor orientation - you may need to adjust the signs
    float heading = atan2(calY, calX) * 180.0 / PI;
    
    // Convert to 0-360 range
    if (heading < 0) {
        heading += 360.0;
    }
    
    // Apply correction factor based on test results
    heading *= yawCorrectionFactor;
    heading += yawOffsetCorrection;
    
    // Normalize again after correction
    if (heading >= 360.0) {
        heading = fmod(heading, 360.0);
    }
    if (heading < 0.0) {
        heading += 360.0;
    }
    
    magneticYaw = heading;
}

void updateGyroYaw() {
    if (!biasCalculated || deltaTime == 0) return;
    
    if (myISM.checkGyroStatus()) {
        myISM.getGyro(&gyroData);
        
        float gyroRate = gyroData.zData - gyroBiasZ;
        gyroFilteredZ = 0.8 * gyroFilteredZ + 0.2 * gyroRate;
        
        if (abs(gyroFilteredZ) > 30.0) {
            gyroYaw += gyroFilteredZ * deltaTime;
            
            while (gyroYaw >= 360.0) gyroYaw -= 360.0;
            while (gyroYaw < 0.0) gyroYaw += 360.0;
        }
    }
}

void updateKalmanFilter() {
    if (deltaTime == 0) return;
    
    // Get gyro rate (already bias corrected)
    float gyroRate = gyroFilteredZ;
    
    // Prediction step
    kalmanYaw += (gyroRate - gyroBias) * deltaTime;
    
    // Normalize angle
    while (kalmanYaw >= 360.0) kalmanYaw -= 360.0;
    while (kalmanYaw < 0.0) kalmanYaw += 360.0;
    
    // Update error covariance
    P[0][0] += deltaTime * (deltaTime * P[1][1] - P[0][1] - P[1][0] + Q_angle);
    P[0][1] -= deltaTime * P[1][1];
    P[1][0] -= deltaTime * P[1][1];
    P[1][1] += Q_gyro * deltaTime;
    
    // Update step (using magnetometer measurement)
    y = magneticYaw - kalmanYaw;
    
    // Handle angle wrapping for innovation
    while (y > 180.0) y -= 360.0;
    while (y < -180.0) y += 360.0;
    
    S = P[0][0] + R_measure;
    
    // Calculate Kalman gain
    K[0] = P[0][0] / S;
    K[1] = P[1][0] / S;
    
    // Update state
    kalmanYaw += K[0] * y;
    gyroBias += K[1] * y;
    
    // Normalize angle
    while (kalmanYaw >= 360.0) kalmanYaw -= 360.0;
    while (kalmanYaw < 0.0) kalmanYaw += 360.0;
    
    // Update error covariance
    float P00_temp = P[0][0];
    float P01_temp = P[0][1];
    
    P[0][0] -= K[0] * P00_temp;
    P[0][1] -= K[0] * P01_temp;
    P[1][0] -= K[1] * P00_temp;
    P[1][1] -= K[1] * P01_temp;
}

void fuseYawEstimates() {
    if (useKalmanFilter) {
        fusedYaw = kalmanYaw;
    } else {
        float angleDiff = magneticYaw - gyroYaw;
        
        // Handle angle wrapping
        while (angleDiff > 180.0) angleDiff -= 360.0;
        while (angleDiff < -180.0) angleDiff += 360.0;
        
        gyroYaw += alpha * angleDiff;
        
        while (gyroYaw >= 360.0) gyroYaw -= 360.0;
        while (gyroYaw < 0.0) gyroYaw += 360.0;
        
        fusedYaw = gyroYaw;
    }
}

void debugMagnetometer() {
    if (!magCalibrated) {
        Serial.println("Please calibrate magnetometer first (command 'c')");
        return;
    }
    
    Serial.println("\n=== MAGNETOMETER DEBUG MODE ===");
    Serial.println("This will show detailed calculations for debugging.");
    Serial.println("Place sensor at 200° and press ENTER...");
    
    waitForEnter();
    
    // Take multiple readings
    float readings[10];
    for (int i = 0; i < 10; i++) {
        myMag.getMeasurementXYZ(&rawMagX, &rawMagY, &rawMagZ);
        
        float rawX = (float)rawMagX - 131072.0;
        float rawY = (float)rawMagY - 131072.0;
        
        float calX = (rawX - magOffsetX) * magScaleX;
        float calY = (rawY - magOffsetY) * magScaleY;
        
        float magnitude = sqrt(calX * calX + calY * calY);
        if (magnitude > 0) {
            calX /= magnitude;
            calY /= magnitude;
        }
        
        float heading = atan2(calY, calX) * 180.0 / PI;
        if (heading < 0) heading += 360.0;
        
        readings[i] = heading;
        
        Serial.print("Sample "); Serial.print(i+1); Serial.print(": ");
        Serial.print("Raw("); Serial.print(rawX, 0); Serial.print(","); Serial.print(rawY, 0); Serial.print(") ");
        Serial.print("Cal("); Serial.print(calX, 3); Serial.print(","); Serial.print(calY, 3); Serial.print(") ");
        Serial.print("Heading: "); Serial.println(heading, 1);
        
        delay(100);
    }
    
    // Calculate average
    float sum = 0;
    for (int i = 0; i < 10; i++) {
        sum += readings[i];
    }
    float avgReading = sum / 10.0;
    
    Serial.print("\nAverage reading at 200°: "); Serial.println(avgReading, 1);
    
    Serial.println("\nNow rotate EXACTLY 90° clockwise to 290° and press ENTER...");
    waitForEnter();
    
    // Take reading at new position
    for (int i = 0; i < 10; i++) {
        myMag.getMeasurementXYZ(&rawMagX, &rawMagY, &rawMagZ);
        
        float rawX = (float)rawMagX - 131072.0;
        float rawY = (float)rawMagY - 131072.0;
        
        float calX = (rawX - magOffsetX) * magScaleX;
        float calY = (rawY - magOffsetY) * magScaleY;
        
        float magnitude = sqrt(calX * calX + calY * calY);
        if (magnitude > 0) {
            calX /= magnitude;
            calY /= magnitude;
        }
        
        float heading = atan2(calY, calX) * 180.0 / PI;
        if (heading < 0) heading += 360.0;
        
        readings[i] = heading;
        delay(100);
    }
    
    sum = 0;
    for (int i = 0; i < 10; i++) {
        sum += readings[i];
    }
    float newReading = sum / 10.0;
    
    Serial.print("Average reading at 290°: "); Serial.println(newReading, 1);
    
    // Calculate the actual rotation
    float actualRotation = newReading - avgReading;
    if (actualRotation < -180.0) actualRotation += 360.0;
    if (actualRotation > 180.0) actualRotation -= 360.0;
    
    Serial.print("Measured rotation: "); Serial.print(actualRotation, 1); Serial.println("°");
    Serial.print("Expected rotation: 90.0°");
    Serial.print("Error: "); Serial.print(actualRotation - 90.0, 1); Serial.println("°");
    
    if (abs(actualRotation - 90.0) > 5.0) {
        Serial.println("\nPossible issues:");
        Serial.println("1. Sensor orientation - check if X/Y axes are swapped");
        Serial.println("2. Calibration quality - recalibrate in interference-free area");
        Serial.println("3. Magnetic interference - move away from metal objects");
        Serial.println("4. atan2 parameters may need sign adjustment");
    }
    
    Serial.println();
}

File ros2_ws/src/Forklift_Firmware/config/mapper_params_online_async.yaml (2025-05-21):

slam_toolbox:
  ros__parameters:
    # Plugin params
    solver_plugin: solver_plugins::CeresSolver
    ceres_linear_solver: SPARSE_NORMAL_CHOLESKY
    ceres_preconditioner: SCHUR_JACOBI
    ceres_trust_strategy: LEVENBERG_MARQUARDT
    ceres_dogleg_type: TRADITIONAL_DOGLEG
    ceres_loss_function: None

    # ROS Parameters
    odom_frame: odom
    map_frame: map
    base_frame: base_link
    scan_topic: /scan
    use_map_saver: true
    mode: mapping #localization

    # if you'd like to immediately start continuing a map at a given pose
    # or at the dock, but they are mutually exclusive, if pose is given
    # will use pose
    #map_file_name: test_steve
    # map_start_pose: [0.0, 0.0, 0.0]
    #map_start_at_dock: true

    debug_logging: false
    throttle_scans: 1
    transform_publish_period: 0.02 #if 0 never publishes odometry
    map_update_interval: 5.0
    resolution: 0.05
    min_laser_range: 0.2 #for rastering images
    max_laser_range: 12.0 #for rastering images
    minimum_time_interval: 0.5
    transform_timeout: 0.2
    tf_buffer_duration: 30.
    stack_size_to_use: 40000000 #// program needs a larger stack size to serialize large maps
    enable_interactive_mode: true

    # General Parameters
    use_scan_matching: true
    use_scan_barycenter: true
    minimum_travel_distance: 0.5
    minimum_travel_heading: 0.5
    scan_buffer_size: 10
    scan_buffer_maximum_scan_distance: 10.0
    link_match_minimum_response_fine: 0.1
    link_scan_maximum_distance: 1.5
    loop_search_maximum_distance: 3.0
    do_loop_closing: true
    loop_match_minimum_chain_size: 10
    loop_match_maximum_variance_coarse: 3.0
    loop_match_minimum_response_coarse: 0.35
    loop_match_minimum_response_fine: 0.45

    # Correlation Parameters - Correlation Parameters
    correlation_search_space_dimension: 0.5
    correlation_search_space_resolution: 0.01
    correlation_search_space_smear_deviation: 0.1

    # Correlation Parameters - Loop Closure Parameters
    loop_search_space_dimension: 8.0
    loop_search_space_resolution: 0.05
    loop_search_space_smear_deviation: 0.03

    # Scan Matcher Parameters
    distance_variance_penalty: 0.5
    angle_variance_penalty: 1.0

    fine_search_angle_offset: 0.00349
    coarse_search_angle_offset: 0.349
    coarse_angle_resolution: 0.0349
    minimum_angle_penalty: 0.9
    minimum_distance_penalty: 0.5
    use_response_expansion: true
    min_pass_through: 2
    occupancy_threshold: 0.1

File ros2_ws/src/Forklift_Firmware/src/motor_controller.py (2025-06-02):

#!/usr/bin/env python3

import rclpy
from rclpy.node import Node
from std_msgs.msg import String
import time

# GPIO control for motors (Raspberry Pi)
try:
    import RPi.GPIO as GPIO
    GPIO_AVAILABLE = True
except ImportError:
    GPIO_AVAILABLE = False
    print("WARNING: RPi.GPIO not available. Motor control will be simulated.")

class MotorControllerNode(Node):
    def __init__(self):
        super().__init__('motor_controller_node')

        # GPIO pin definitions (matching your original script)
        self.IN1 = 18  # Left motor forward
        self.IN2 = 17  # Left motor backward
        self.IN3 = 22  # Right motor forward
        self.IN4 = 23  # Right motor backward

        # Store GPIO availability as instance variable
        self.gpio_available = GPIO_AVAILABLE

        # Motor state tracking
        self.current_command = "stop"
        self.last_command_time = time.time()
        self.command_timeout = 1.0  # Stop motors if no command received for 1 second

        # Setup GPIO
        self.setup_gpio()

        # Subscribe to motor commands topic
        self.motor_cmd_sub = self.create_subscription(
            String,
            '/motor_commands',
            self.motor_command_callback,
            10
        )

        # Publisher for motor status feedback
        self.motor_status_pub = self.create_publisher(String, '/motor_status', 10)

        # Timer for safety timeout check
        self.safety_timer = self.create_timer(0.1, self.safety_check)  # Check every 100ms

        # Log startup
        self.get_logger().info("🤖 " + "=" * 50)
        self.get_logger().info("🤖 MOTOR CONTROLLER NODE STARTED")
        self.get_logger().info("🤖 " + "=" * 50)
        self.get_logger().info(f"📌 GPIO Pins - Left Motor: IN1={self.IN1}, IN2={self.IN2}")
        self.get_logger().info(f"📌 GPIO Pins - Right Motor: IN3={self.IN3}, IN4={self.IN4}")
        self.get_logger().info(f"⏱️  Safety timeout: {self.command_timeout}s")
        self.get_logger().info("📡 Subscribed to: /motor_commands")
        self.get_logger().info("📢 Publishing to: /motor_status")
        self.get_logger().info("✅ Ready to receive motor commands!")
        self.get_logger().info("🤖 " + "=" * 50)

    def setup_gpio(self):
        """Setup GPIO pins for motor control"""
        if not self.gpio_available:
            self.get_logger().warn("⚠️  GPIO not available - running in SIMULATION mode")
            return

        try:
            # Setup GPIO
            GPIO.setmode(GPIO.BCM)
            GPIO.setwarnings(False)

            # Setup motor pins as outputs
            GPIO.setup(self.IN1, GPIO.OUT)
            GPIO.setup(self.IN2, GPIO.OUT)
            GPIO.setup(self.IN3, GPIO.OUT)
            GPIO.setup(self.IN4, GPIO.OUT)

            # Initialize all pins to LOW (motors stopped)
            GPIO.output(self.IN1, GPIO.LOW)
            GPIO.output(self.IN2, GPIO.LOW)
            GPIO.output(self.IN3, GPIO.LOW)
            GPIO.output(self.IN4, GPIO.LOW)

            self.get_logger().info("✅ GPIO setup completed successfully")

        except Exception as e:
            self.get_logger().error(f"❌ Failed to setup GPIO: {e}")
            self.get_logger().error("🔄 Switching to simulation mode")
            # Set class attribute instead of global
            self.gpio_available = False

    def motor_command_callback(self, msg):
        """Handle incoming motor commands"""
        command = msg.data.lower().strip()
        self.last_command_time = time.time()

        # Log received command
        self.get_logger().info(f"📨 Received command: '{command}'")

        # Execute the appropriate motor function
        if command == "move_fwd" or command == "forward":
            self.move_forward()
        elif command == "move_bkw" or command == "backward":
            self.move_backward()
        elif command == "rotate_cw" or command == "turn_right":
            self.turn_right()
        elif command == "rotate_acw" or command == "turn_left":
            self.turn_left()
        elif command == "stop":
            self.stop_motors()
        else:
            self.get_logger().warn(f"⚠️  Unknown command: '{command}' - stopping motors for safety")
            self.stop_motors()

        # Update current command
        self.current_command = command

        # Publish motor status
        self.publish_motor_status(command)

    def move_forward(self):
        """Move robot forward"""
        if self.gpio_available:
            GPIO.output(self.IN1, GPIO.HIGH)  # Left motor forward
            GPIO.output(self.IN2, GPIO.LOW)
            GPIO.output(self.IN3, GPIO.HIGH)  # Right motor forward
            GPIO.output(self.IN4, GPIO.LOW)
            self.get_logger().info("🏃 Moving FORWARD ↑")
        else:
            self.get_logger().info("🏃 SIMULATED: Moving FORWARD ↑")

    def move_backward(self):
        """Move robot backward"""
        if self.gpio_available:
            GPIO.output(self.IN1, GPIO.LOW)   # Left motor backward
            GPIO.output(self.IN2, GPIO.HIGH)
            GPIO.output(self.IN3, GPIO.LOW)   # Right motor backward
            GPIO.output(self.IN4, GPIO.HIGH)
            self.get_logger().info("🔙 Moving BACKWARD ↓")
        else:
            self.get_logger().info("🔙 SIMULATED: Moving BACKWARD ↓")

    def turn_left(self):
        """Turn robot left (anti-clockwise)"""
        if self.gpio_available:
            GPIO.output(self.IN1, GPIO.LOW)   # Left motor stop/slow
            GPIO.output(self.IN2, GPIO.HIGH)
            GPIO.output(self.IN3, GPIO.HIGH)  # Right motor forward
            GPIO.output(self.IN4, GPIO.LOW)
            self.get_logger().info("↺ Turning LEFT (Anti-clockwise)")
        else:
            self.get_logger().info("↺ SIMULATED: Turning LEFT (Anti-clockwise)")

    def turn_right(self):
        """Turn robot right (clockwise)"""
        if self.gpio_available:
            GPIO.output(self.IN1, GPIO.HIGH)  # Left motor forward
            GPIO.output(self.IN2, GPIO.LOW)
            GPIO.output(self.IN3, GPIO.LOW)   # Right motor stop/slow
            GPIO.output(self.IN4, GPIO.HIGH)
            self.get_logger().info("↻ Turning RIGHT (Clockwise)")
        else:
            self.get_logger().info("↻ SIMULATED: Turning RIGHT (Clockwise)")

    def stop_motors(self):
        """Stop all motors"""
        if self.gpio_available:
            GPIO.output(self.IN1, GPIO.LOW)
            GPIO.output(self.IN2, GPIO.LOW)
            GPIO.output(self.IN3, GPIO.LOW)
            GPIO.output(self.IN4, GPIO.LOW)
            self.get_logger().info("🛑 Motors STOPPED ⏹️")
        else:
            self.get_logger().info("🛑 SIMULATED: Motors STOPPED ⏹️")

    def safety_check(self):
        """Safety timeout check - stop motors if no recent commands"""
        current_time = time.time()
        time_since_last_command = current_time - self.last_command_time
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

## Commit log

2025-02-17 adding file for getting intial scans
    [pyvenv.cfg]
2025-02-27 made changes in data.py to display LIDAR output
2025-02-27 LIDAR repo added
2025-03-12 motor debugging
2025-04-03 ros2 package added rplidar
    [pyvenv.cfg]
2025-05-19 added the IMU library for python
2025-05-21 slam implementation started
    [my_robot.urdf.xacro, robot.urdf]
2025-05-22 added imu_publisher and updated IMU_SEN-19895
    [my_robot.urdf.xacro, robot.urdf]
2025-05-22 added imu_publisher and updated the IMU_SEN-19895
    [my_robot.urdf.xacro]
2025-05-22 adding pwm and more features for teleop
2025-05-22 updated static slam
    [my_robot.urdf.xacro]
2025-05-23 removed build files
    [my_robot.urdf.xacro]
2025-05-23 fixed imu readings
2025-05-23 added UWB IMU fusion
2025-05-24 updates imu
    [my_robot.urdf.xacro]
2025-05-24 updated imu again
2025-05-27 mpu uwb fuse in simulation
2025-05-27 added camera publisher
2025-05-27 updated camera init
2025-05-28 motor script issue fixed
    [motor_controller.py]
2025-06-02 changed motor controller
2025-06-09 Add goal navigator and improve position controls Quad Demo The commit includes: - Create goal navigator node for robot position control - Update UWB anchor positions for better accuracy - Add navigat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
2025-06-25 Added STEP and STL files of all 3D Models developed for the Smart Forklift so far.
    [N20_Motor_Mount_Lower.step, N20_Motor_Mount_Lower.stl, N20_Motor_Mount_Upper.step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]
2025-06-25 Added spacer files.
    [4mm-screw_spacer_OD-6.5mm_ID-4.2mm_75mm.step, 4mm-screw_spacer_OD-6.5mm_ID-4.2mm_75mm.stl]
